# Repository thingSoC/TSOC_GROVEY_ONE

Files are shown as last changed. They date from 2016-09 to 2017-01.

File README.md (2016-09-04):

# TSOC_GROVEY_ONE
**TSOC_GROVEY_ONE** is a ATMEGA328 based board, an Embedded Module for thingSoC compatible with the Arduino IDE.

The **TSOC_GROVEY_ONE** allows you to connect [thingSoC](http://thingsoc.github.io/), [Mikrobus](http://www.mikroe.com/mikrobus/), 
and/or [Grove System](http://www.seeedstudio.com/blog/2016/03/09/tutorial-intro-to-grove-connectors-for-arduinoraspberry-pi-projects/) 
Modules all at the same time, using the Arduino Development environment, with the the ATMEGA328P processor.
This gives you maximum flexiblity for sensor and actuator, selection and reuse. 

The thingSoC "Grovey Series" was designed as "Everyday Electronics", a no-frills, low cost, approach to modular embedded product design.
thingSoC boards are similar in size to most break-out-boards (BOBs), but feature a standardized stacking pinout, as well as an I2C metadata store (EEPROM)
to indicate what peripherals are installed.

---------------------------------------

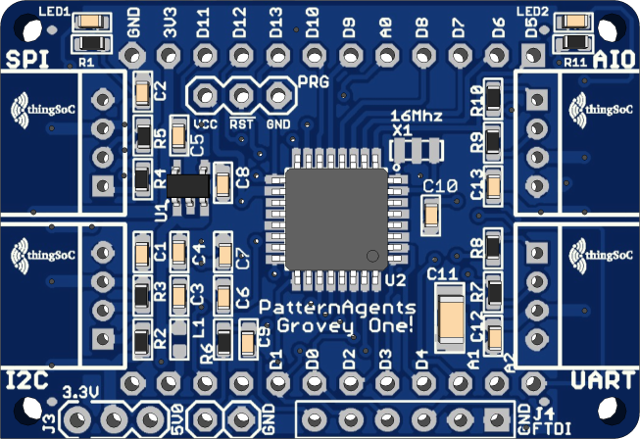
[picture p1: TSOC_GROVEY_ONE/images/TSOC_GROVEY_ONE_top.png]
thingSoC GROVEY_ONE
[TSOC_GROVEY_ONE](https://github.com/thingSoC/TSOC_GROVEY_ONE/)

* [thingSoC Compliant Module](http://www.thingsoc.com)
* [Mikrobus Compatible Module](http://www.mikroe.com/mikrobus/) 
* 5V Nominal Power Input
* 5V or 3.3V Operation
* Supports Analog  Inputs  (ADC) 
* Supports Digital Outputs (GPIO)
* Supports Digital Inputs  (GPIO)
* Supports I2C Interface
* Supports UART Interface
* Supports SPI Interface

---------------------------------------
## Example Applications

* [Weather Sensor](http://www.mikroe.com/click/weather/) BOSCH BME280 Temp, Humidity, Air Pressure
* [Methane Sensor](http://www.mikroe.com/click/methane/) MQ-4 Sensor for Methane (CH4) 
* [Air Quality Sensor](http://www.mikroe.com/click/air-quality/) MQ-135 Sensor for Harmful Gasses
* [Lightning Sensor](http://www.mikroe.com/click/thunder/) AS3935 Lighting Strike Detector
* [Controlled Relay](http://www.mikroe.com/click/relay/) G6D1AASI Power Relay Control Module

---------------------------------------
## 3D Model (Sketchup)

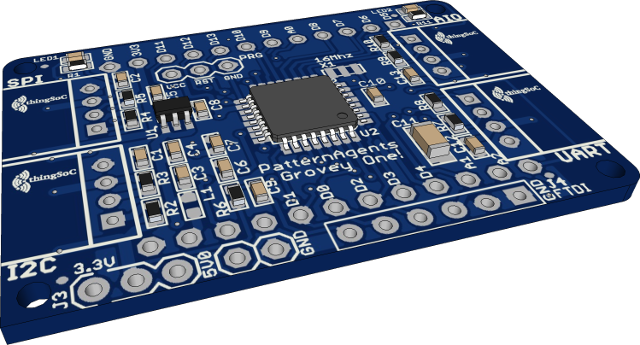
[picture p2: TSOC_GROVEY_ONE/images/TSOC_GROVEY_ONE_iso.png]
thingSoC TSOC_GROVEY_ONE


---------------------------------------
## Project Status

* 09/02/2016 : Revision 2.0 Release for PCB fab

## Revision 2.0 Notes: ##

* Add FTDI Connector

---------------------------------------

## Documentation Index <a name="documentation_index"/>

[Quick Start Guide](https://github.com/thingSoC/TSOC_GROVEY_ONE/blob/master/TSOC_GROVEY_ONE/docs/QuickStart.md)

[User Guide](https://github.com/thingSoC/TSOC_GROVEY_ONE/blob/master/TSOC_GROVEY_ONE/docs/UserGuide.md)

[Theory of Operation](https://github.com/thingSoC/TSOC_GROVEY_ONE/blob/master/TSOC_GROVEY_ONE/docs/TheoryOfOperation.md)

[thingSoC Organization Website](http://thingSoC.github.io)

[thingSoC FAQ - Frequently Asked Questions](http://thingsoc.github.io/support/faq.html)

---------------------------------------

[  
*thingSoC*](http://thingsoc.github.io)

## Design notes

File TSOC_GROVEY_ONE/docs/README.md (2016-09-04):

**TSOC_GROVEY_ONE** is a ATMEGA328 based board, an Embedded Module for thingSoC compatible with the Arduino IDE.

The **TSOC_GROVEY_ONE** allows you to connect [thingSoC](http://thingsoc.github.io/), [Mikrobus](http://www.mikroe.com/mikrobus/), 
and/or [Grove System](http://www.seeedstudio.com/blog/2016/03/09/tutorial-intro-to-grove-connectors-for-arduinoraspberry-pi-projects/) 
Modules all at the same time, using the Arduino Development environment, with the the ATMEGA328P processor.
This gives you maximum flexiblity for sensor and actuator, selection and reuse. 

[thingSoC GROVEY_ONETSOC_GROVEY_ONE](https://github.com/thingSoC/TSOC_GROVEY_ONE/)

The thingSoC "Grovey Series" was designed as "Everyday Electronics", a no-frills, low cost, approach to modular embedded product design.
thingSoC boards are similar in size to most break-out-boards (BOBs), but feature a standardized stacking pinout, as well as an I2C metadata store (EEPROM)
to indicate what peripherals are installed.

---------------------------------------

## Documentation Index <a name="documentation_index"/>

[[TSOC_GROVEY_ONE Quick Start Guide](https://github.com/thingSoC/TSOC_GROVEY_ONE/blob/master/TSOC_GROVEY_ONE/docs/QuickStart.md)

[TSOC_GROVEY_ONE User Guide](https://github.com/thingSoC/TSOC_GROVEY_ONE/blob/master/TSOC_GROVEY_ONE/docs/UserGuide.md)

[TSOC_GROVEY_ONE Theory of Operation](https://github.com/thingSoC/TSOC_GROVEY_ONE/blob/master/TSOC_GROVEY_ONE/docs/TheoryOfOperation.md)

[thingSoC Organization Website](http://thingSoC.github.io)

[thingSoC FAQ - Frequently Asked Questions](http://thingsoc.github.io/support/faq.html)

---------------------------------------

[  
*thingSoC*](http://thingsoc.github.io)

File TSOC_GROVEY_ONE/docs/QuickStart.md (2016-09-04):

# TSOC_GROVEY_ONE Quick Start Guide

Welcome! <br>
The **TSOC_GROVEY_ONE**  Quick Start Guide is a series of quick steps to try out your new board.

---------------------------------------

## Quick Start Guide <a name="quickstartguide_index"/>

1. Plug the **TSOC_GROVEY_ONE** into another thingSoC board, such as the Teensy3x or Grovey_WiFi
2. Plug a Peripheral into the **TSOC_GROVEY_ONE** and note which port number (there are four ports).
3. Open the Arduino IDE and Select "File -> Examples -> TSOC_GROVEY_ONE -> Port X  
   where X is the Port number that your installed your peripheral into
4. Follow the instructions on your screen to configure the TSOC_GROVEY_ONE for your application.

[thingSoC GROVEY_ONETSOC_GROVEY_ONE](https://github.com/thingSoC/TSOC_GROVEY_ONE/)

The thingSoC "Grovey Series" was designed as "Everyday Electronics", a no-frills, low cost, approach to modular embedded product design.
thingSoC boards are similar in size to most break-out-boards (BOBs), but feature a standardized stacking pinout, as well as an I2C metadata store (EEPROM)
to indicate what peripherals are installed.

---------------------------------------

## Documentation Index <a name="documentation_index"/>

[TSOC_GROVEY_ONE Quick Start Guide](https://github.com/thingSoC/TSOC_GROVEY_ONE/blob/master/TSOC_GROVEY_ONE/docs/QuickStart.md)

[TSOC_GROVEY_ONE User Guide](https://github.com/thingSoC/TSOC_GROVEY_ONE/blob/master/TSOC_GROVEY_ONE/docs/UserGuide.md)

[TSOC_GROVEY_ONE Theory of Operation](https://github.com/thingSoC/TSOC_GROVEY_ONE/blob/master/TSOC_GROVEY_ONE/docs/TheoryOfOperation.md)

[thingSoC Organization Website](http://thingSoC.github.io)

[thingSoC FAQ - Frequently Asked Questions](http://thingsoc.github.io/support/faq.html)

---------------------------------------

[  
*thingSoC*](http://thingsoc.github.io)

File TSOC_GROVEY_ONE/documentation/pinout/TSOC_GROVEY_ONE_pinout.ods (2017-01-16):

 |  |  |  | A3 | D5 | PWR | GND | D0 | D1 | PWR | GND
 |  |  |  | ANA | PWM | VCC | GND | RXD | TXD | VCC | GND
DEFAULT | PORT | ADC | PWM |  |  |  |  |  |  |  |  | DEFAULT | PORT | ADC | PWM | LEGEND
USER LED | D13 |  |  |  |  |  |  |  |  |  |  |  |  |  |  | POWER/GROUND PINS
IO2 | D5 |  | D5 |  |  |  |  |  |  |  |  | RI | A6 | A6 |  | DIGITAL PINS
IO1 | D6 |  | D6 |  |  |  |  |  |  |  |  | DCD | A2 | A2 |  | ANALOG/ADC PINS
SS2 | D7 |  |  |  |  |  |  |  |  |  |  | DSR | A1 | A1 |  | PWM PINS
SS1 | D8 |  |  |  |  |  |  |  |  |  |  | DTR | D4 |  |  | TOUCH PINS
IRQ | A0 | A0 |  |  |  |  |  |  |  |  |  | RTS | D3 |  | D3 | UART PINS
ATN | D9 |  | D9 |  |  |  |  |  |  |  |  | CTS | D2 |  |  | PROGRAM/JTAG/DEBUG PINS
SSEL | D10 |  | D10 |  |  |  |  |  |  |  |  | RXD | D0 |  |  | I2C BUS PINS
SCK | D13 | (PGM) |  |  |  |  |  |  |  |  |  | TXD | D1 |  |  | SPI BUS PINS
MISO | D12 | (PGM) |  |  |  |  |  |  |  |  |  | SCL | A5 | A5
MOSI | D11 | (PGM) | D11 |  |  |  |  |  |  |  |  | SDA | A4 | A4
3.3 VOLTS | 3V3 |  |  |  |  |  |  |  |  |  |  | 5.0 VOLTS | 5V0
GROUND | GND |  |  |  |  |  |  |  |  |  |  | GND | GND
POWER LED | VCC
 |  |  |  | GND | VCC | MOSI | SCK | GND | VCC | SDA | SCL |  |  |  | PatternAgents
 |  |  |  | GND | PWR | D11 | D13 | GND | PWR | A4 | A5 |  |  |  | http://github.com/thingsoc/
 |  |  |  |  |  |  |  |  |  |  |  |  |  |  | TSOC_GROVEY_ONE

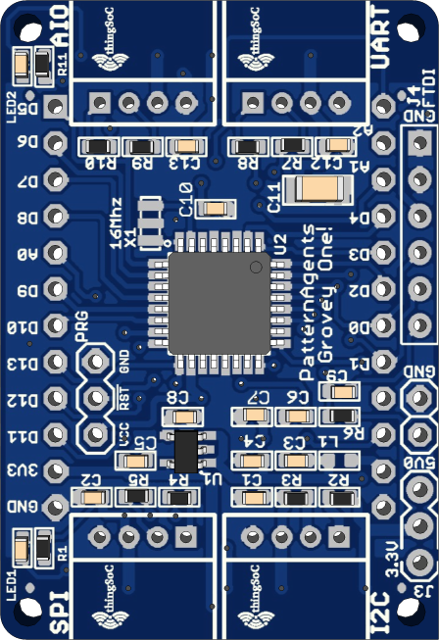
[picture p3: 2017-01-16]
TSOC_GROVEY_ONE/images/TSOC_GROVEY_ONE_pinout.png

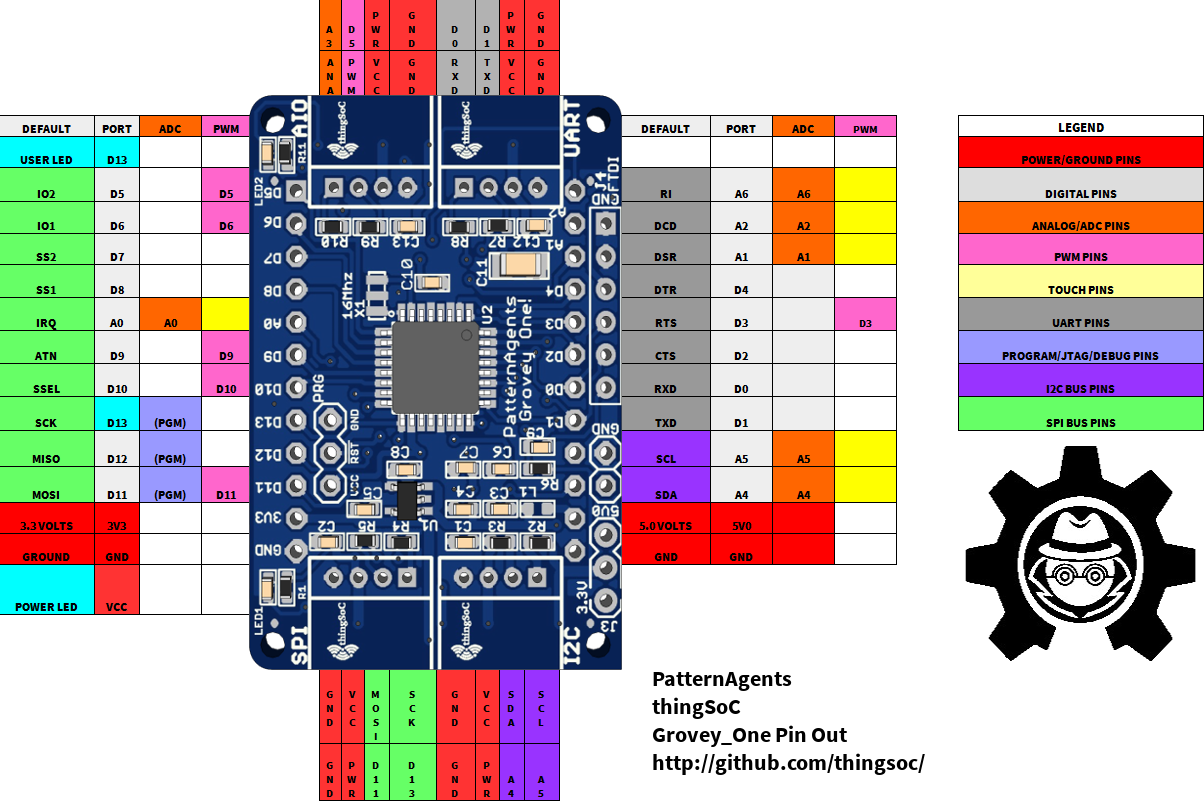
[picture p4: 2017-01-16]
TSOC_GROVEY_ONE/documentation/pinout/TSOC_GROVEY_ONE_pinout.png

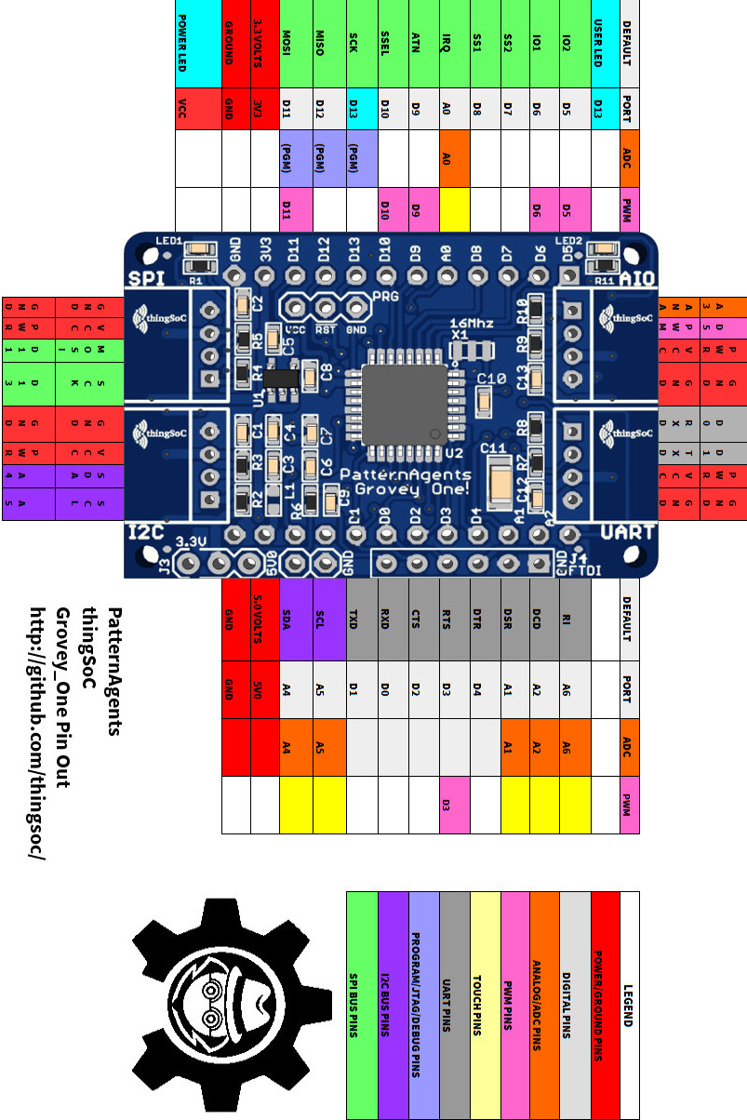
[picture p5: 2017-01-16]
TSOC_GROVEY_ONE/documentation/pinout/TSOC_GROVEY_ONE_pinout_long.jpg

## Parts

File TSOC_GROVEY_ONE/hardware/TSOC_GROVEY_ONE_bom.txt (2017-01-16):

Partlist exported from U:/PatternAgents/eagle/TSOC_Modules/TSOC_GROVEY_ONE/TSOC_GROVEY_ONE/TSOC_GROVEY_ONE.sch at 11/9/2016 3:23:07 PM
RFevison 2.0

Part  Value                Device                                          Package              Description                           BOM     MPN                 VALUE               
C1    100nf                CERAMIC-100NF-50V-10%-X7R(0603)                 C0603                302010138                                     CC0603KRX7R9BB104   100nf               
C2    100nf                CERAMIC-100NF-50V-10%-X7R(0603)                 C0603                302010138                                     CC0603KRX7R9BB104   100nf               
C3    10uf                 CERAMIC-10UF-10V-10%-X5R(0603)                  C0603                302010103                                     CC0603KRX5R6BB106   10uf                
C4    100nf                CERAMIC-100NF-50V-10%-X7R(0603)                 C0603                302010138                                     CC0603KRX7R9BB104   100nf               
C5    10uf                 CERAMIC-10UF-10V-10%-X5R(0603)                  C0603                302010103                                     CC0603KRX5R6BB106   10uf                
C6    100nf                CERAMIC-100NF-50V-10%-X7R(0603)                 C0603                302010138                                     CC0603KRX7R9BB104   100nf               
C7    100nf                CERAMIC-100NF-50V-10%-X7R(0603)                 C0603                302010138                                     CC0603KRX7R9BB104   100nf               
C8    470Pf                CERAMIC-100NF-50V-10%-X7R(0603)                 C0603                302010138                                     CC0603KRX7R9BB104   100nf               
C9    100nf                CERAMIC-100NF-50V-10%-X7R(0603)                 C0603                302010138                                     CC0603KRX7R9BB104   100nf               
C10   100nf                CERAMIC-100NF-50V-10%-X7R(0603)                 C0603                302010138                                     CC0603KRX7R9BB104   100nf               
C11   22uF                 CAP-1206                                        EIA-1206             Ceramic Capacitor SMD                                                                 
C12   100nf                CERAMIC-100NF-50V-10%-X7R(0603)                 C0603                302010138                                     CC0603KRX7R9BB104   100nf               
C13   100nf                CERAMIC-100NF-50V-10%-X7R(0603)                 C0603                302010138                                     CC0603KRX7R9BB104   100nf               
R1    1K 1/10W             SMD-RES-1K-5%-1/10W(0603)                       R0603                301010291                                     RC0603JR-071KL      1K 1/10W            
R2    2.2K                 SMD-RES-2.2K-5%-1/10W(0603)                     R0603                301010124                                     RC0603JR-072K2L     2.2K                
R3    2.2K                 SMD-RES-2.2K-5%-1/10W(0603)                     R0603                301010124                                     RC0603JR-072K2L     2.2K                
R4    1K 1/10W             SMD-RES-1K-5%-1/10W(0603)                       R0603                301010291                                     RC0603JR-071KL      1K 1/10W            
R5    1K 1/10W             SMD-RES-1K-5%-1/10W(0603)                       R0603                301010291                                     RC0603JR-071KL      1K 1/10W            
R6    10K 1/10W            SMD-RES-10K-5%-1/10W(0603)                      R0603                301010293                                     RC0603JR-0710KL     10K 1/10W           
R7    1K 1/10W             SMD-RES-1K-5%-1/10W(0603)                       R0603                301010291                                     RC0603JR-071KL      1K 1/10W            
R8    1K 1/10W             SMD-RES-1K-5%-1/10W(0603)                       R0603                301010291                                     RC0603JR-071KL      1K 1/10W            
R9    1K 1/10W             SMD-RES-1K-5%-1/10W(0603)                       R0603                301010291                                     RC0603JR-071KL      1K 1/10W            
R10   1K 1/10W             SMD-RES-1K-5%-1/10W(0603)                       R0603                301010291                                     RC0603JR-071KL      1K 1/10W            
R11   1K 1/10W             SMD-RES-1K-5%-1/10W(0603)                       R0603                301010291                                     RC0603JR-071KL      1K 1/10W            
L1    120OHM-500MA         SMD-FERRITE-CHIP-120-OHM-500MA(0603)            L0603                303030001                                     BLM18AG121SN1D      120OHM-500MA        
X1    16MHZ                SMD-RESONATOR-16MHZ-15PF-0.5%-40R(3P-3.2X1.3MM) X3-SMD-3.6X1.3X0.8MM 306030002                                     CSTCE16M0V53-R0     16MHZ               
LED1  GREEN-0603           SMD-LED-CLEAR-GREEN(0603)                       LED-0603             304090043                                     19-217-G7C-AN1P2-3T GREEN-0603          
LED2  RED-0603             SMD-LED-CLEAR-GREEN(0603)                       LED-0603             304090043                                     19-217-G7C-AN1P2-3T GREEN-0603          
U1    MIC5219              PMIC-LDO                                        SOT-23-5                                                           MIC5219-3.3V        MIC5219-3.3V
U2    ATMEGA328            ATMEGA168                                       TQFP32-08                                                                                                  
AIO   4P-2.0-90D           GROVE-CONNECTOR-DIP-90D(4P-2.0)                 HW4-2.0-90D          320110034                                                         4P-2.0-90D          
I2C   4P-2.0-90D           GROVE-CONNECTOR-DIP-90D(4P-2.0)                 HW4-2.0-90D          320110034                                                         4P-2.0-90D          
SPI   4P-2.0-90D           GROVE-CONNECTOR-DIP-90D(4P-2.0)                 HW4-2.0-90D          320110034                                                         4P-2.0-90D          
UART  4P-2.0-90D           GROVE-CONNECTOR-DIP-90D(4P-2.0)                 HW4-2.0-90D          320110034                                                         4P-2.0-90D          
J3    NO                   JMP-3-NO-PTH                                    JMP-3-NO-PTH-2.54    Three Terminal Jumper - Normally Open                                                 
J4    6p-2.54              DIP-BLACK-MALE-HEADER(6P-2.54)                  H6-2.54              320020078                                     P125-1106A1BS116A1  6p-2.54

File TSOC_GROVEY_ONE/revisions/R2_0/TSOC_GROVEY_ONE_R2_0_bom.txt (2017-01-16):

Partlist exported from U:/PatternAgents/eagle/TSOC_Modules/TSOC_GROVEY_ONE/TSOC_GROVEY_ONE/revisions/R2_0/TSOC_GROVEY_ONE_R2_0_gerbers/TSOC_GROVEY_ONE.sch at 12/29/2016 11:41:01 AM

Qty Value             Device                                          Package              Parts                                 Description                           
1                     JMP-2-NO                                        JMP-2-NO             A7                                    Two Terminal Jumper - Normally Open   
2                     M01PTH                                          1X01                 5V0, GND                              Header 1                              
1                     M03PTH                                          1X03                 PRG                                   Header 3                              
9   100nf             CERAMIC-100NF-50V-10%-X7R(0603)                 C0603                C1, C2, C4, C6, C7, C9, C10, C12, C13 302010138                             
1   10K 1/10W         SMD-RES-10K-5%-1/10W(0603)                      R0603                R6                                    301010293                             
2   10uf              CERAMIC-10UF-10V-10%-X5R(0603)                  C0603                C3, C5                                302010103                             
1   120OHM-500MA      SMD-FERRITE-CHIP-120-OHM-500MA(0603)            L0603                L1                                    303030001                             
1   16MHZ             SMD-RESONATOR-16MHZ-15PF-0.5%-40R(3P-3.2X1.3MM) X3-SMD-3.6X1.3X0.8MM X1                                    306030002                             
8   1K 1/10W          SMD-RES-1K-5%-1/10W(0603)                       R0603                R1, R4, R5, R7, R8, R9, R10, R11      301010291                             
2   2.2K              SMD-RES-2.2K-5%-1/10W(0603)                     R0603                R2, R3                                301010124                             
1   22uF              CAP-1206                                        EIA-1206             C11                                   Ceramic Capacitor SMD                 
1   470Pf             CERAMIC-100NF-50V-10%-X7R(0603)                 C0603                C8                                    302010138                             
4   4P-2.0-90D        GROVE-CONNECTOR-DIP-90D(4P-2.0)                 HW4-2.0-90D          AIO, I2C, SPI, UART                   320110034                             
1   6p-2.54           DIP-BLACK-MALE-HEADER(6P-2.54)                  H6-2.54              J4                                    320020078                             
1   AP2112K-3.3V      V_REG_LDOSMD                                    SOT23-5              U1                                    Voltage Regulator LDO                 
1   ATMEGA328         ATMEGA168                                       TQFP32-08            U2                                                                          
4   FIDUCIALUFIDUCIAL FIDUCIALUFIDUCIAL                               MICRO-FIDUCIAL       FID1, FID2, FID3, FID4                Fiducial Alignment Points             
1   GREEN-0603        SMD-LED-CLEAR-GREEN(0603)                       LED-0603             LED1                                  304090043                             
1   NO                JMP-3-NO-PTH                                    JMP-3-NO-PTH-2.54    J3                                    Three Terminal Jumper - Normally Open 
1   RED-0603          SMD-LED-CLEAR-GREEN(0603)                       LED-0603             LED2                                  304090043                             
1   TSOC-24-BB        TSOC-24-BB                                      TSOC-BB-S24          TSOC                                  thingSoC Twenty-Four(24) Pin Socket   
1   TSOC-LOGO-LRG     TSOC-LOGO-LRG                                   TSOC-LOGO-LRG        U$102                                 thingSoC Logo                         
3   TSOC-LOGO-SMALL   TSOC-LOGO-SMALL                                 TSOC-LOGO-SML        U$1, U$101, U$103                     thingSoC Logo                         
1   TSOC-PCB-SINGLE   TSOC-PCB-SINGLE                                 TSOC-BB-BRD-DIM      $$U$1                                 thingSoC PCB Outlines

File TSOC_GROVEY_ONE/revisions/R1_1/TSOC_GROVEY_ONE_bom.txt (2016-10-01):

Partlist exported from U:/PatternAgents/eagle/TSOC_Modules/TSOC_GROVEY_ONE/TSOC_GROVEY_ONE/TSOC_GROVEY_ONE.sch Revison 1.1 at 9/29/2016 11:40:15 AM

Qty Value             Device                                          Package            Parts                                 Description                           
9   100nf             CERAMIC-100NF-50V-10%-X7R(0603)         C0603              C1, C2, C4, C6, C7, C9, C10, C12, C13 302010138                             
1   10K 1/10W         SMD-RES-10K-5%-1/10W(0603)              R0603              R6                                    301010293                             
2   10uf              CERAMIC-10UF-10V-10%-X5R(0603)          C0603              C3, C5                                302010103                             
2   120OHM-500MA      SMD-FERRITE-CHIP-120-OHM-500MA(0603)    L0603              L1, L2                                303030001                             
1   16MHZ             SMD-RESONATOR-16MHZ-15PF-0.5%-40R       X3-SMD             X1                                    306030002                             
8   1K 1/10W          SMD-RES-1K-5%-1/10W(0603)               R0603              R1, R11,R4, R5, R7, R8, R9, R10       301010291                             
2   2.2K              SMD-RES-2.2K-5%-1/10W(0603)             R0603              R2, R3                                301010124                             
1   22uF              CAP-1206                                EIA-1206           C11                                   Ceramic Cap                
1   470Pf             CERAMIC-100NF-50V-10%-X7R(0603)         C0603              C8                                    302010138                             
1   GREEN-0603        SMD-LED-CLEAR-GREEN(0603)               LED-0603           LED1                                  304090043                             
1   RED-0603          SMD-LED-CLEAR-GREEN(0603)               LED-0603           LED2                                  304090043                             
1   ATMEGA328         ATMEGA168                               TQFP32-08          U2                                                                          
1   MIC5219 3.3V      V_REG_MIC52193.3V                       SOT23-5            U1                                    V_REG MIC5219                         

Optional Parts (Do NOT Install on Production Boards)
----------------------------------------------------------------------------------------------------------------------------------------------
4   4P-2.0-90D        GROVE-CONNECTOR-DIP-90D(4P-2.0)         HW4-2.0-90D        J1, J2, J5, J6                        320110034                             
1   6p-2.54           DIP-BLACK-MALE-HEADER(6P-2.54)          H6-2.54            J4                                    320020078                             
1   NO                JMP-3-NO-PTH                            JMP-3-NO-PTH-2.54  J3                                    Three Terminal Jumper 
1                     M03PTH                                  1X03               PRG                                   Header 3                              
1                     M01PTH                                  1X01               GND                                   Header 1                              
1                     JMP-2-NO                                JMP-2-NO           A7                                    Two Terminal Jumper 
----------------------------------------------------------------------------------------------------------------------------------------------

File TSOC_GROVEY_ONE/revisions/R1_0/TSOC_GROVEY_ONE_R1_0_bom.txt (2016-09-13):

Partlist exported from U:/PatternAgents/eagle/TSOC_Modules/TSOC_GROVEY_ONE/TSOC_GROVEY_ONE/TSOC_GROVEY_ONE.sch Revison 1.0 at 9/2/2016 10:40:15 AM

Qty Value             Device                                          Package            Parts                                 Description                           
9   100nf             CERAMIC-100NF-50V-10%-X7R(0603)         C0603              C1, C2, C4, C6, C7, C9, C10, C12, C13 302010138                             
1   10K 1/10W         SMD-RES-10K-5%-1/10W(0603)              R0603              R6                                    301010293                             
2   10uf              CERAMIC-10UF-10V-10%-X5R(0603)          C0603              C3, C5                                302010103                             
2   120OHM-500MA      SMD-FERRITE-CHIP-120-OHM-500MA(0603)    L0603              L1, L2                                303030001                             
1   16MHZ             SMD-RESONATOR-16MHZ-15PF-0.5%-40R       X3-SMD             X1                                    306030002                             
2   1K 1/10W          SMD-RES-1K-5%-1/10W(0603)               R0603              R1, R11                               301010291                             
2   2.2K              SMD-RES-2.2K-5%-1/10W(0603)             R0603              R2, R3,                               301010124                             
1   22uF              CAP-1206                                EIA-1206           C11                                   Ceramic Cap                
1   470Pf             CERAMIC-100NF-50V-10%-X7R(0603)         C0603              C8                                    302010138                             
1   GREEN-0603        SMD-LED-CLEAR-GREEN(0603)               LED-0603           LED1                                  304090043                             
1   RED-0603          SMD-LED-CLEAR-GREEN(0603)               LED-0603           LED2                                  304090043                             
4   4P-2.0-90D        GROVE-CONNECTOR-DIP-90D(4P-2.0)         HW4-2.0-90D        J1, J2, J5, J6                        320110034                             
1   ATMEGA328         ATMEGA168                               TQFP32-08          U2                                                                          
1   MIC5219 3.3V      V_REG_MIC52193.3V                       SOT23-5            U1                                    V_REG MIC5219                         

Optional Parts (Do NOT Install on Production Boards)
----------------------------------------------------------------------------------------------------------------------------------------------
6   2.2K              SMD-RES-2.2K-5%-1/10W(0603)             R0603              R4, R5, R7, R8, R9, R10               301010124                             
1   6p-2.54           DIP-BLACK-MALE-HEADER(6P-2.54)          H6-2.54            J4                                    320020078                             
1   NO                JMP-3-NO-PTH                            JMP-3-NO-PTH-2.54  J3                                    Three Terminal Jumper 
1                     M03PTH                                  1X03               PRG                                   Header 3                              
1                     M01PTH                                  1X01               GND                                   Header 1                              
1                     JMP-2-NO                                JMP-2-NO           A7                                    Two Terminal Jumper 
----------------------------------------------------------------------------------------------------------------------------------------------

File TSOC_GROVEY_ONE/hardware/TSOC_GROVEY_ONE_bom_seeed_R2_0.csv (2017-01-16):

Part/Designator | Manufacture Part Number/Seeed SKU | Quantity
C1,C2,C4,C6,C7,C9,C10,C12,C13 | 302010138 | 9
C3,C5 | 302010103 | 2
C8 | 302010141 | 1
C11 | 302010183 | 1
R2,R3 | 301010124 | 2
R1,R4,R5,R7,R8,R9,R10,R11 | 301010291 | 8
R6 | 301010293 | 1
LED1 | 304090043 | 1
LED2 | 304090045 | 1
L1 | 303030001 | 1
X1 | 306030002 | 1
U1 | 310030046 | 1
U2 | 1030060P1 | 1
AIO,I2C,SPI,UART | 3470140P1 | 4
J4 | 320020078 | 1
J3 | 320020079 | 1

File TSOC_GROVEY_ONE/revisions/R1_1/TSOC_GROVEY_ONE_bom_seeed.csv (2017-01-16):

Part/Designator | Manufacture Part Number/Seeed SKU | Quantity
C1,C2,C4,C6,C7,C9,C10,C12,C13 | 302010138 | 9
C3,C5 | 302010103 | 2
C8 | 302010141 | 1
C11 | 302010183 | 1
R1,R11 | 301010291 | 2
R4,R5,R7,R8,R9,R10 | 301010124 | 6
R2,R3,R6 | 301010293 | 3
LED1 | 304090043 | 1
LED2 | 304090045 | 1
L1 | 303030001 | 1
X1 | 306030002 | 1
U1 | AP2112K-3.3TRG1 | 1
U2 | 310010049 | 1
AIO,I2C,SPI,UART | 320110034 | 4
J1,J2 | PPTC121LFBN-RC | 2
J3 | 320020079 | 1
J4 | 320020078 | 1

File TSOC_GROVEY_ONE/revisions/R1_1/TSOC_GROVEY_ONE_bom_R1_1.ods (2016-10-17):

Qty | Value | Device | Package | Parts | Seeed Pt# | Digikey # | Digikey $/ea | MOQ | # have
9 | 100nf | CERAMIC-100NF-50V-10%-X7R(0603) | C0603 | C1, C2, C4, C6, C7, C9, C10, C12, C13 | 302010138 | 490-1524-2-ND | $0.00368 | 4000 | 3736
1 | 470Pf | CERAMIC-100NF-50V-10%-X7R(0603) | C0603 | C8 |  | 1276-1168-2-ND | $0.00451 | 4000 | Minireel 467
2 | 10uf | CERAMIC-10UF-10V-10%-X5R(0603) | C0603 | C3, C5 | 302010103 | 490-10474-2-ND | $0.02688 | 4000 | 6
1 | 22uF | CAP-1206 | EIA-1206 | C11 |  | 478-9946-1-ND | $0.38520 | 25 | Minireel 188
8 | 1K 1/10W | SMD-RES-1K-5%-1/10W(0603) | R0603 | R1, R4, R5, R7, R8, R9, R10, R11 | 301010291 | RMCF0603JT1K00 | $0.00158 | 5000 | 4922
2 | 2.2K | SMD-RES-2.2K-5%-1/10W(0603) | R0603 | R2, R3 | 301010124 | RMCF0603JT2K20TR-ND | $0.00158 | 5000 | 4872
1 | 10K 1/10W | SMD-RES-10K-5%-1/10W(0603) | R0603 | R6 | 301010293 | RMCF0603JT10K0TR-ND | $0.00158 | 5000 | 4864
1 | 120OHM-500MA | SMD-FERRITE-CHIP-120-OHM-500MA(0603) | L0603 | L1 | 303030001
1 | 16MHZ | SMD-RESONATOR-16MHZ-15PF-0.5%-40R(3P-3.2X1.3MM) | X3-SMD-3.6X1.3X0.8MM | X1 | 306030002 | 490-1198-1-ND | $0.48 | 1 | 5
1 | GREEN-0603 | SMD-LED-CLEAR-GREEN(0603) | LED-0603 | LED1 |  | 475-3118-1-ND | $0.35 | 1 | 15
1 | RED-0603 | SMD-LED-CLEAR-RED(0603) | LED-0603 | LED2 | 304090043 | 475-2506-1-ND | $0.35 | 1 | 8
1 | MIC5219 3.3V | V_REG_MIC52193.3V | SOT23-5 | U1 |  | 576-1281-1-ND | $0.89 | 1 | 30
1 | ATMEGA328 | ATMEGA168 | TQFP32-08 | U2 |  | ATMEGA328P-AURCT-ND | $3.81 | 1 | 4
1 | TSOC-PCB-SINGLE | TSOC-PCB-SINGLE | TSOC-BB-BRD-DIM | PCB |  |  | $4.00
2 | F12X1 | CONN HEADER FEM 12POS.1' SGL TIN | F12X1 | J7, J8 | S6100-ND | S6100-ND | $0.98 | 1 | 12
4 | 4P-2.0-90D | GROVE-Universal CONNECTOR-DIP-90D(4P-2.0) | HW4-2.0-90D | AIO, I2C, SPI, UART | 320110034 | SEEED110990037 | $0.15
1 | 6p-2.54 | DIP-BLACK-MALE-HEADER(6P-2.54) | H6-2.54 | J4 | 320020078 |  | $0.25 | 1

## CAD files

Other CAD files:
TSOC_GROVEY_ONE/eagleUp/TSOC_GROVEY_ONE.skp

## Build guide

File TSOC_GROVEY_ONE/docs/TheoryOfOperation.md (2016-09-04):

# TSOC_GROVEY_ONE Theory of Operation

**TSOC_GROVEY_ONE** is a ATMEGA328 based board, an Embedded Module for thingSoC compatible with the Arduino IDE.

The **TSOC_GROVEY_ONE** allows you to connect [thingSoC](http://thingsoc.github.io/), [Mikrobus](http://www.mikroe.com/mikrobus/), 
and/or [Grove System](http://www.seeedstudio.com/blog/2016/03/09/tutorial-intro-to-grove-connectors-for-arduinoraspberry-pi-projects/) 
Modules all at the same time, using the Arduino Development environment, with the the ATMEGA328P processor.
This gives you maximum flexiblity for sensor and actuator, selection and reuse. 

[thingSoC GROVEY_ONETSOC_GROVEY_ONE](https://github.com/thingSoC/TSOC_GROVEY_ONE/)

The thingSoC "Grovey Series" was designed as "Everyday Electronics", a no-frills, low cost, approach to modular embedded product design.
thingSoC boards are similar in size to most break-out-boards (BOBs), but feature a standardized stacking pinout, as well as an I2C metadata store (EEPROM)
to indicate what peripherals are installed.

* [Supported by the Arduino IDE](https://www.arduino.cc/) 
* [thingSoC Compliant Module](http://www.thingsoc.com)
* [Mikrobus Compatible Module](http://www.mikroe.com/mikrobus/) 

---------------------------------------

## Theory of Operation <a name="theory_index"/>

The **TSOC_GROVEY_ONE** supports a single "thingSoC" socket with 3.3 Volt Level signaling.

### Page A : ThingSoC Interface <a name="PAGEA"/>

Schematic Page A

Limitations: 

### Page B : I2C Hub Controller <a name="PAGEB"/>

Schematic Page B

### Page C <a name="PAGEC"/>

Schematic Page C

### Page D <a name="PAGED"/>

Schematic Page D

---------------------------------------

## Documentation Index <a name="documentation_index"/>

[[TSOC_GROVEY_ONE Quick Start Guide](https://github.com/thingSoC/TSOC_GROVEY_ONE/blob/master/TSOC_GROVEY_ONE/docs/QuickStart.md)

[TSOC_GROVEY_ONE User Guide](https://github.com/thingSoC/TSOC_GROVEY_ONE/blob/master/TSOC_GROVEY_ONE/docs/UserGuide.md)

[TSOC_GROVEY_ONE Theory of Operation](https://github.com/thingSoC/TSOC_GROVEY_ONE/blob/master/TSOC_GROVEY_ONE/docs/TheoryOfOperation.md)

[thingSoC Organization Website](http://thingSoC.github.io)

[thingSoC FAQ - Frequently Asked Questions](http://thingsoc.github.io/support/faq.html)
[ESP8266 Community](https://github.com/esp8266/Arduino)

---------------------------------------

[  
*thingSoC*](http://thingsoc.github.io)

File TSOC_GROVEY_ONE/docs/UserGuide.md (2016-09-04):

# TSOC_GROVEY_ONE User Guide

**TSOC_GROVEY_ONE** is a four(4) port I2C Hub/Switch board, an Embedded Module for thingSoC.

The **TSOC_GROVEY_ONE** can operate at either 3.3V or 5V, and can also level translate 3.3V processor I2C bus to 5V peripherals when needed.

The **TSOC_GROVEY_ONE** allows you to connect [thingSoC](http://thingsoc.github.io/), [Mikrobus](http://www.mikroe.com/mikrobus/), 
and/or [Grove System](http://www.seeedstudio.com/blog/2016/03/09/tutorial-intro-to-grove-connectors-for-arduinoraspberry-pi-projects/) 
Modules all at the same time, with any processor module.
This gives you maximum flexiblity for sensor and actuator selection, and reuse. 

---------------------------------------

## User Guide <a name="userguide_index"/>

[thingSoC GROVEY_ONETSOC_GROVEY_ONE](https://github.com/thingSoC/TSOC_GROVEY_ONE/)

---------------------------------------

## Documentation Index <a name="documentation_index"/>

[TSOC_GROVEY_ONE Quick Start Guide](https://github.com/thingSoC/TSOC_GROVEY_ONE/blob/master/TSOC_GROVEY_ONE/docs/QuickStart.md)

[TSOC_GROVEY_ONE User Guide](https://github.com/thingSoC/TSOC_GROVEY_ONE/blob/master/TSOC_GROVEY_ONE/docs/UserGuide.md)

[TSOC_GROVEY_ONE Theory of Operation](https://github.com/thingSoC/TSOC_GROVEY_ONE/blob/master/TSOC_GROVEY_ONE/docs/TheoryOfOperation.md)

[thingSoC Organization Website](http://thingSoC.github.io)

[thingSoC FAQ - Frequently Asked Questions](http://thingsoc.github.io/support/faq.html)

---------------------------------------

[  
*thingSoC*](http://thingsoc.github.io)

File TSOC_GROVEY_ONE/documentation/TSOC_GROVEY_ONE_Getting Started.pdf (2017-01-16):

### Welcome to the thingSoC® Grovey One

The TSOC_GROVEY_ONE is an Arduino Uno compatible board, based on the Atmel ATMEGA328P chip, in an Embedded Module format for the new thingSoC, Internet of Things open source hardware standard.
Getting Started :
The TSOC_GROVEY_ONE is very flexible, and there are a number of different ways to power and reprogram the board, including using a thingSoC USBUART, or other "FTDI" type USB to UART adapters, as well as JTAG/SWD/SPI interfaces for "bare metal" programming.

Using a Li-Po Battery or Wall Power (5V) Adapter :
1) Set the VCC Jumper (Jx) to 3.3 Volts (left position as shown)
2) Using either a thingSoC USB power cable, connect a 5V power source to the Grovey One as shown below :

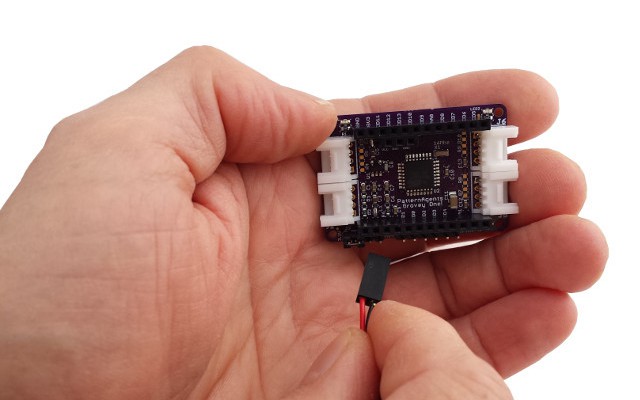
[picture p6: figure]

3) Note that this is the prefered combination for using 3.3 Volt Grove and Mikrobus peripherals, as it provides the correct voltage levels for all 3.3 Volt peripherals.
4) LED2 will illuminate (indicating VCC is powered), and LED1 (D13) will begin to blink slowly.

Using a Standard "FTDI" USB to UART Adapter :
1) Set the VCC Jumper (Jx) to either 3.3 Volts (bottom position)
or 5.0 Volt (top position) depending on you choice of peripherals.
Note that you can't mix voltages, the system is either 3.3 Volts or 5.0 Volts on ALL pins.
2) Plug an "FTDI" type USB to UART into the Grovey One such as the
Sparkfun 5.0 Volt "FTDI Basic" for 5.0 Volt VCC, or the
Sparkfun 3.3 Volt "FTDI Basic" for 3.3 Volt VCC,
and connect the USB cable to your computer.
Note that we use a six (6) pin right angle connector below, or you can just plug it in vertically.

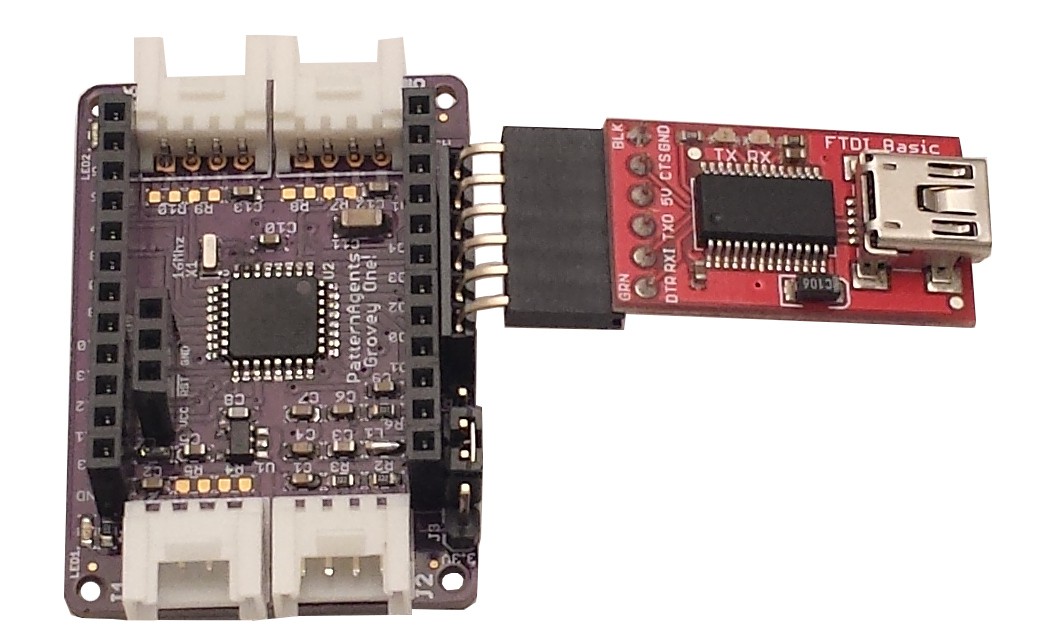
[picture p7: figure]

3) In the Arduino IDE, select the "Tools -> Board" type as "Arduino Pro or Pro Mini"
4) In the Arduino IDE, select the "Tools -> Processor" type as either
"ATMEGA328 5V 16Mhz" or "ATMEGA328 3.3V 8Mhz" depending on your VCC jumper setting.
5) In the Arduino IDE, select the "Tools -> Port" as COMx: where X is your FTDI adapter.
6) Now you are ready to program your Grovey One using the Arduino IDE.

Using an ICSP Programmer for Bare Metal Programming :

The TSOC_GROVEY_ONE board comes preloaded with the OPTIBOOT bootloader for Arduino, but if you prefer to do bare metal programming, connect an ICSP programmer as shown below. NOTE: the pinout is NOT the same as the default Arduino Pro board (due to space limitations).

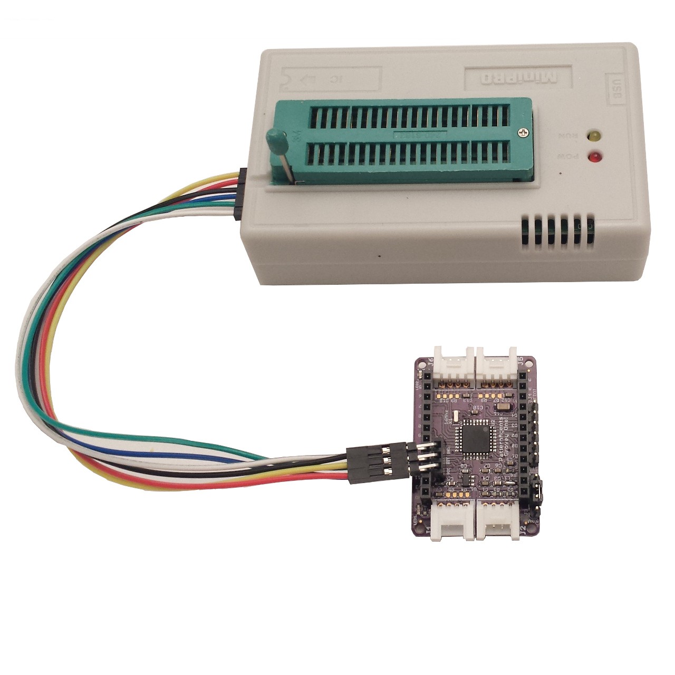
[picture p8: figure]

Grovey One
ICSP Pinout
| VCC - | - D11 |
| RST - | - D12 |
| GND - | - D13 |

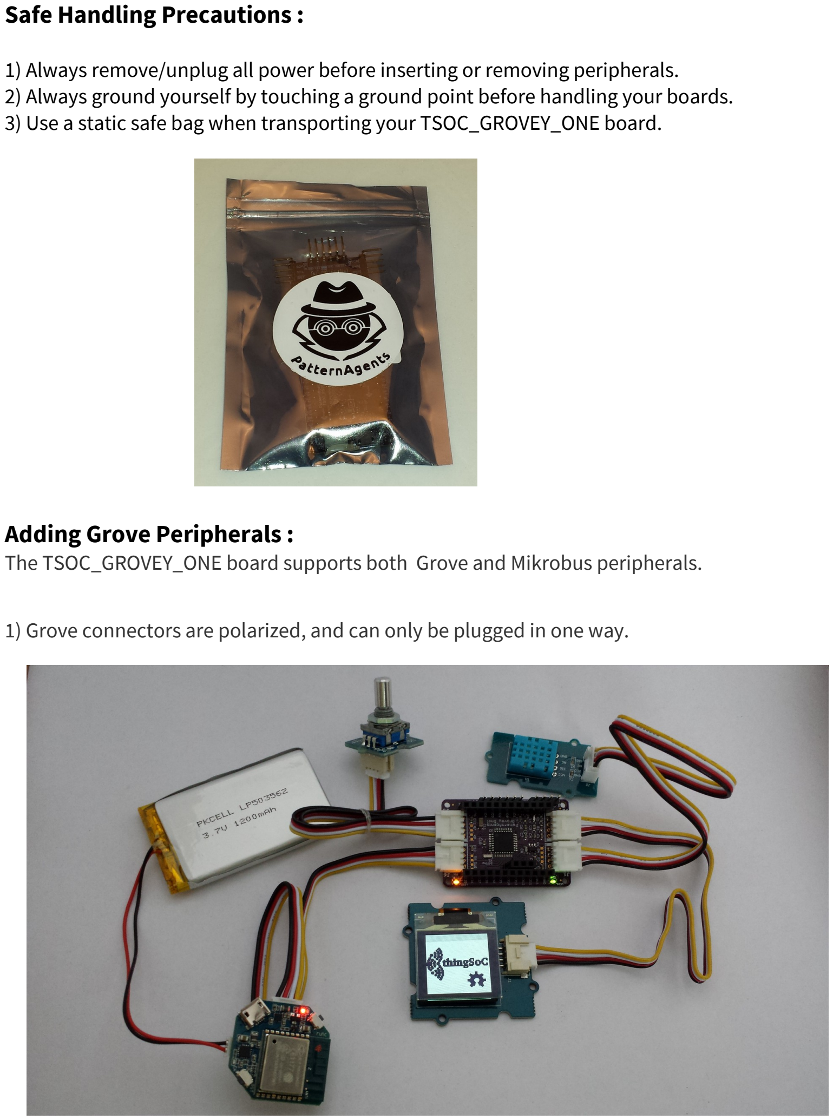
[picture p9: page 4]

Safe Handling Precautions :

1) Always remove/unplug all power before inserting or removing peripherals.
2) Always ground yourself by touching a ground point before handling your boards.
3) Use a static safe bag when transporting your TSOC_GROVEY_ONE board.

Adding Grove Peripherals :
The TSOC_GROVEY_ONE board supports both Grove and Mikrobus peripherals.
1) Grove connectors are polarized, and can only be plugged in one way.

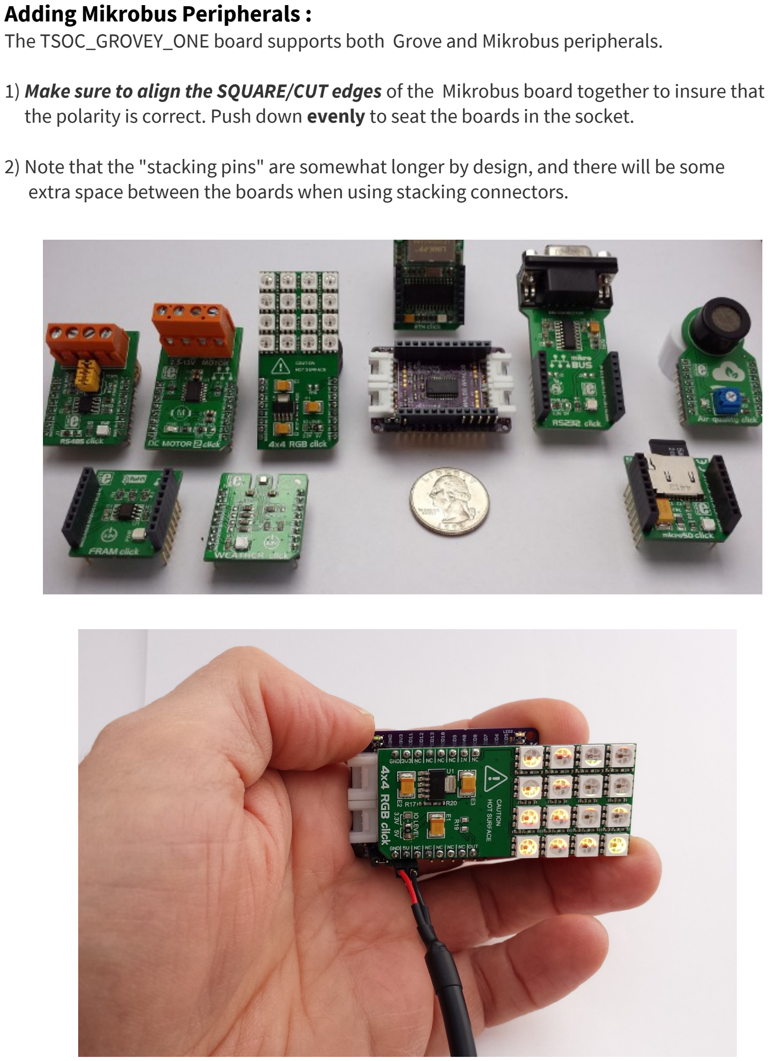
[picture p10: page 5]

Adding Mikrobus Peripherals :
The TSOC_GROVEY_ONE board supports both Grove and Mikrobus peripherals.
1) Make sure to align the SQUARE/CUT edges of the Mikrobus board together to insure that the polarity is correct. Push down evenly to seat the boards in the socket.
2) Note that the "stacking pins" are somewhat longer by design, and there will be some extra space between the boards when using stacking connectors.

### thingSoC® Grovey One Arduino Examples :

### Default Firmware :

1) The Grovey One comes preloaded with the basic "Blink" project. LED1 will blink slowly, indicating the sketch is running.

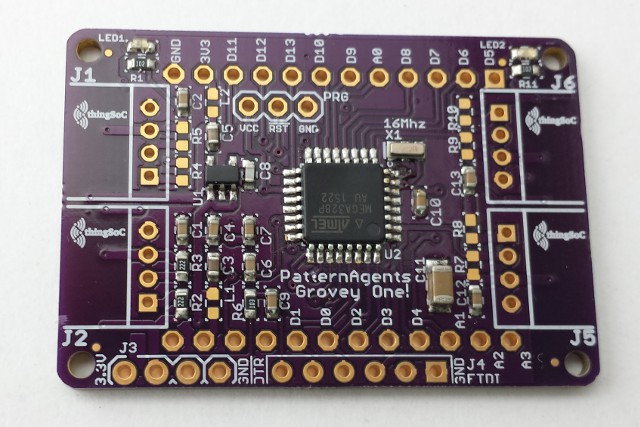
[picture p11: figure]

### For more information and examples :

Complete documentation, including schematics, layouts, gerbers, and Bill of Materials (BOM) are available on the thingSoC website at :

https://github.com/thingSoC/TSOC_GROVEY_ONE/tree/master/TSOC_GROVEY_ONE (https://github.com/thingSoC/TSOC_PSoC4L/tree/master/TSOC_PSoC4L)

There is also a project Wiki available for asking questions and more information at :

https://github.com/thingSoC/TSOC_GROVEY_ONE/wiki (https://github.com/thingSoC/TSOC_PSoC4L/wiki)

thingSoC® Grovey One Features :
The TSOC_GROVEY_ONE is a low cost, embeddable module featuring an ATMEGA328P device :
- Atmel ATMEGA328P (AVR) Processor
- 8 or 16 Mhz operation
- 3.3 Volt or 5.0 Volt operation
- 32 KiB FLASH memory
- 2 KiB SRAM
- 1 KiB EEPROM
- 3.3 Volt onboard voltage regulator
- 10-bit Analog to Digital Converter (8 Channels)
- Touch Sensing (8 Channels)
- SPI (1 Channel)
- I2C (1 Channel)
- UART (1 Channel)
- Power and USER LEDs
- thingSoC Compliant Module
- Mikrobus Compatible Module (http://www.mikroe.com/mikrobus/)

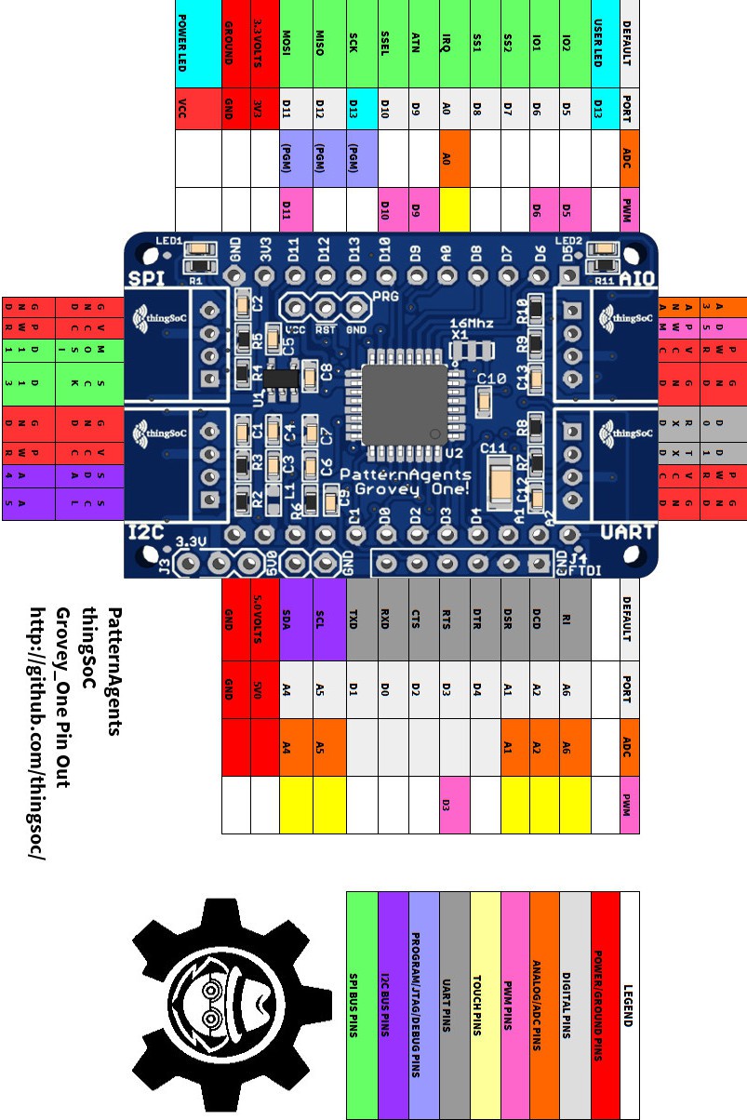
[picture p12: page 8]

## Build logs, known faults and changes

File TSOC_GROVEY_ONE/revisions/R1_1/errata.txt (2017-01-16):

Errata :

1) UART Silkscreen text reverese TXD/RXD - signals are okay

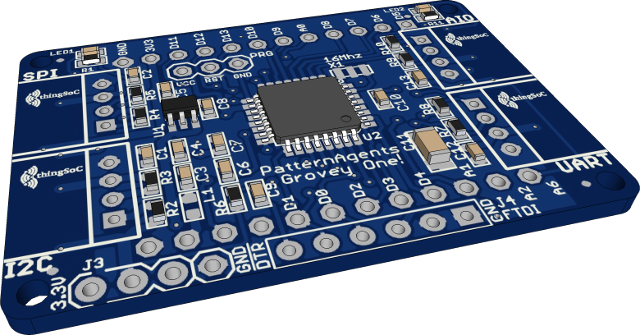
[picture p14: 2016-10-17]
TSOC_GROVEY_ONE/revisions/R1_1/images/TSOC_GROVEY_ONE_iso.png

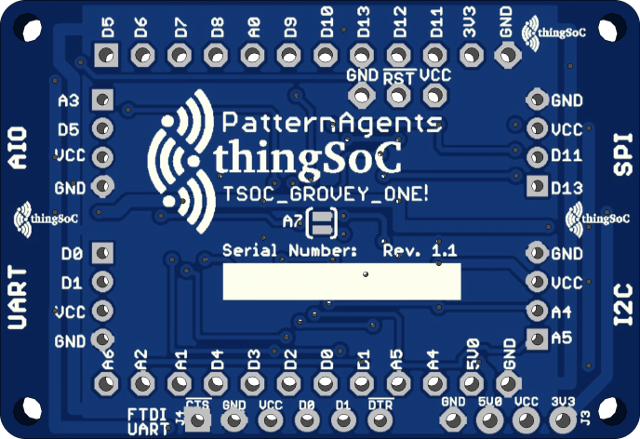
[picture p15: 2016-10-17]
TSOC_GROVEY_ONE/revisions/R1_1/images/TSOC_GROVEY_ONE_bot.png

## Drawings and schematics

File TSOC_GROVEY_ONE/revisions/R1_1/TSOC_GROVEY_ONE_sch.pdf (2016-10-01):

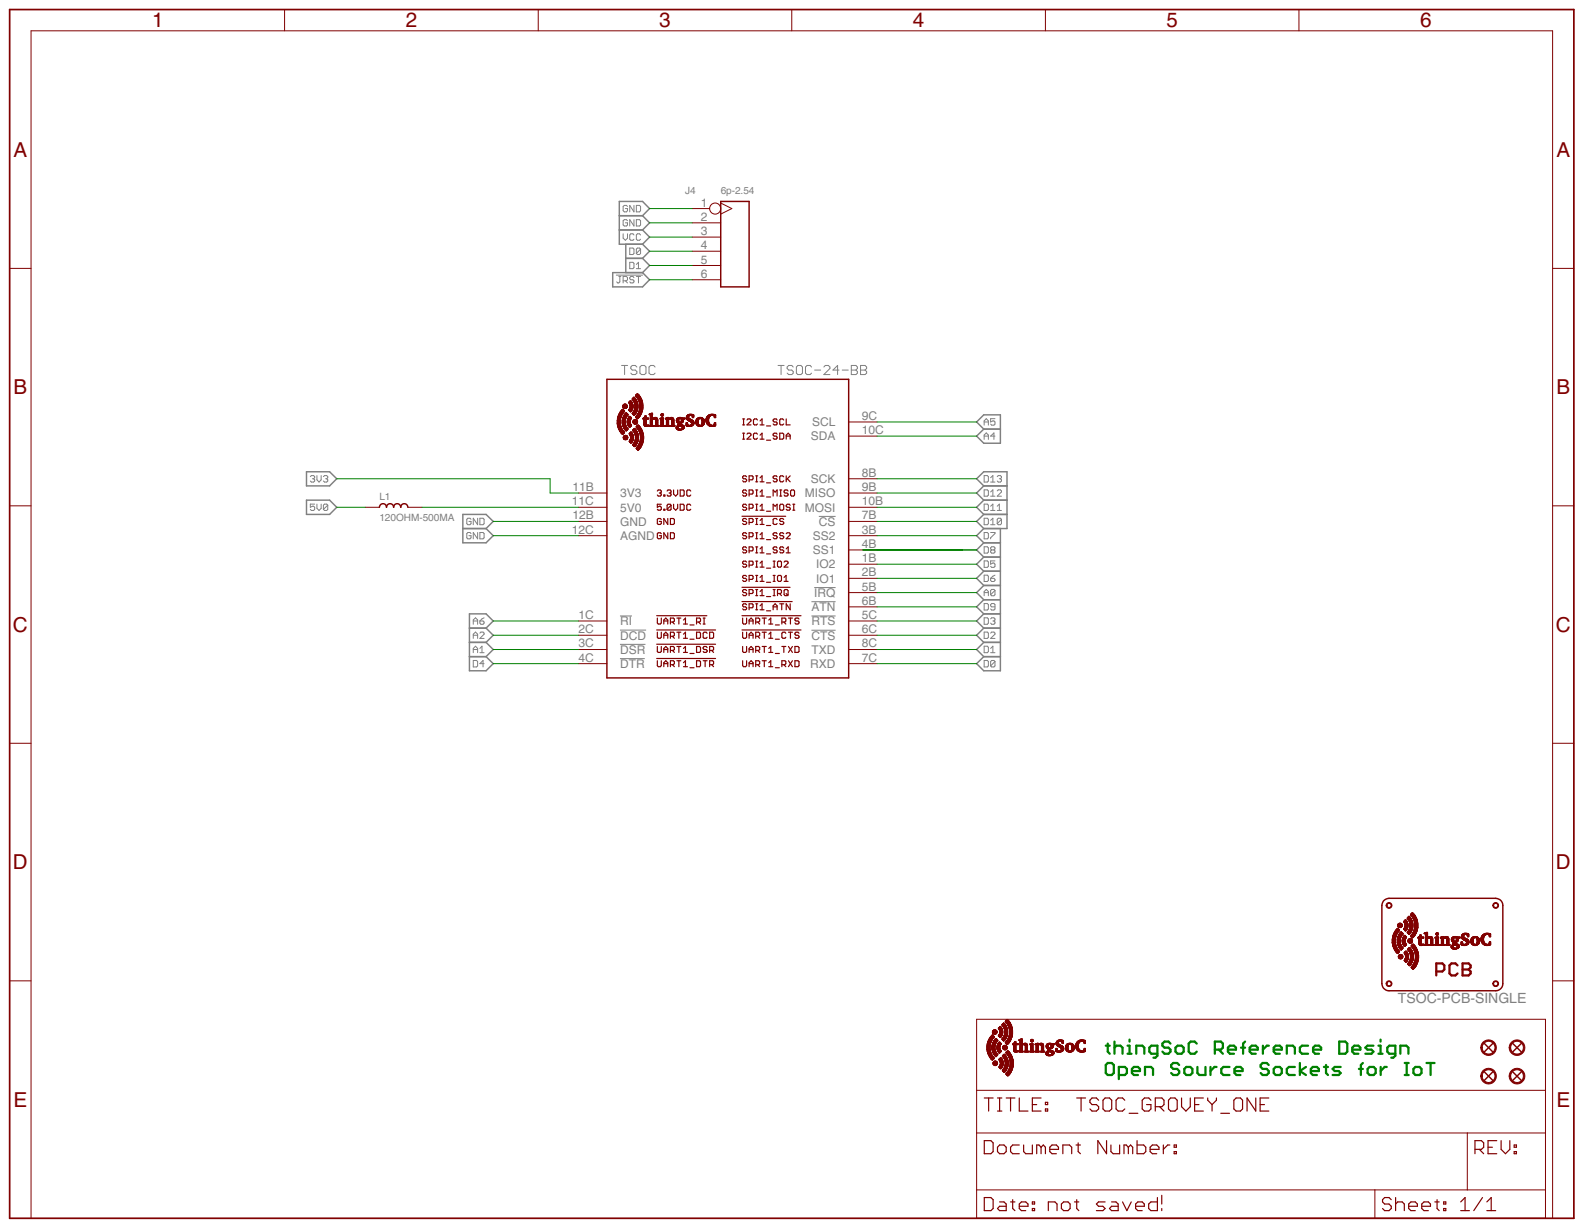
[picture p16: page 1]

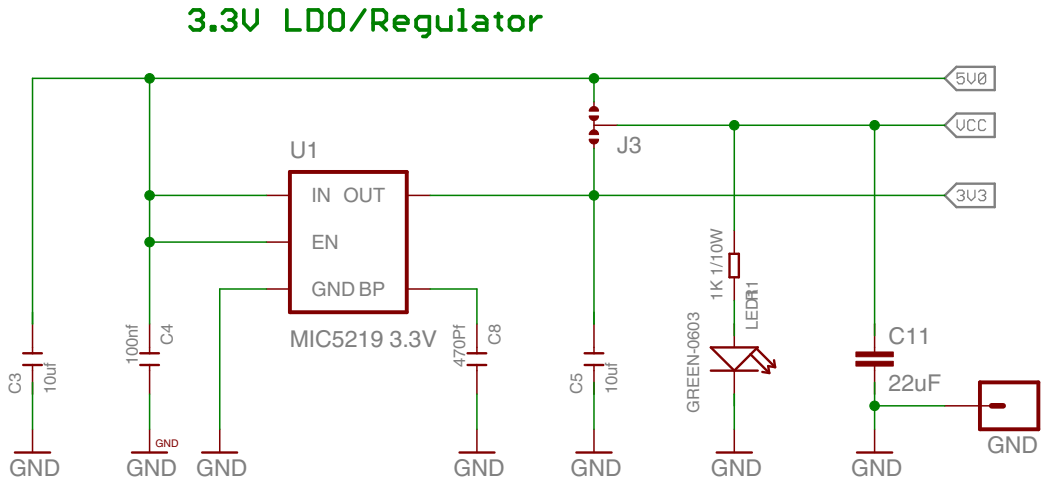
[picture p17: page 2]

100nf GND GND GND GND

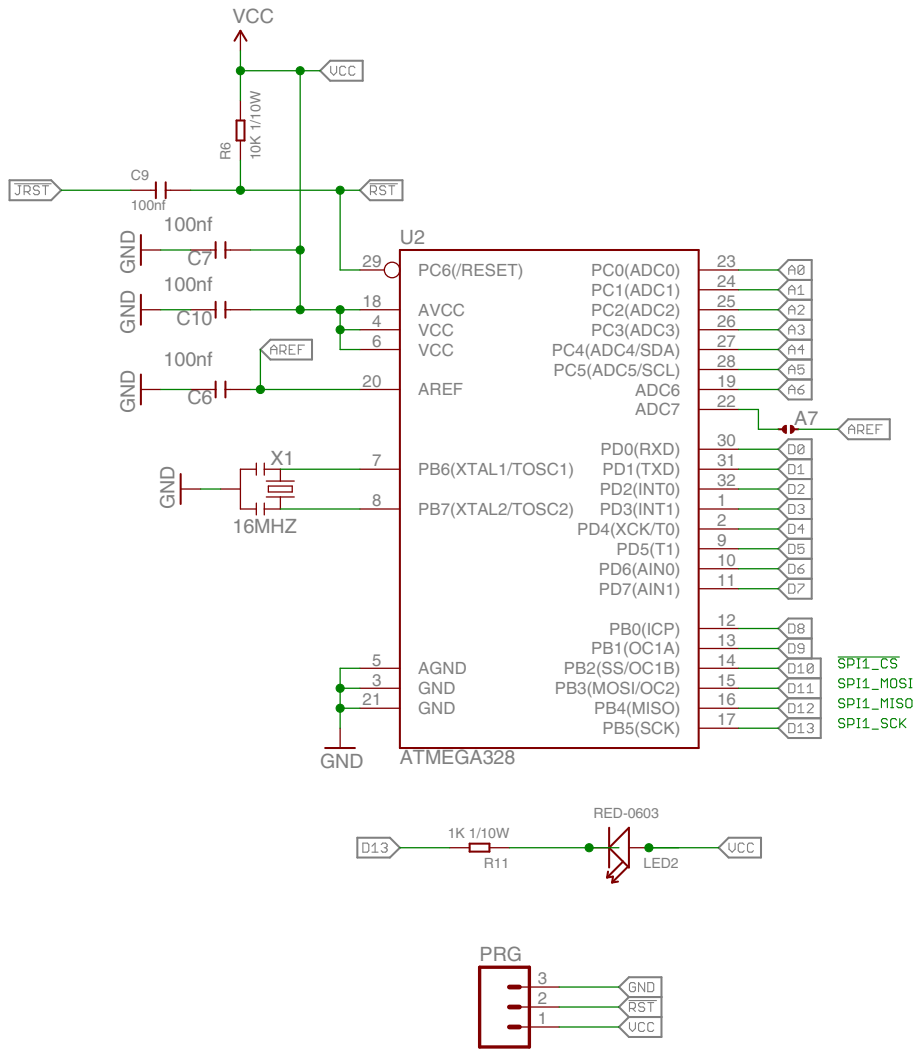
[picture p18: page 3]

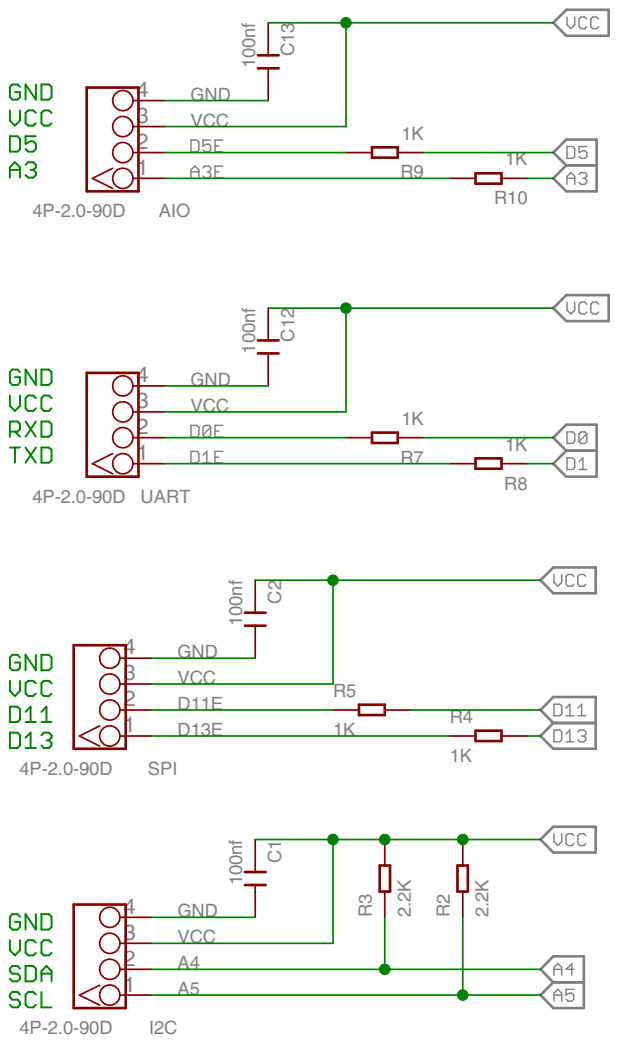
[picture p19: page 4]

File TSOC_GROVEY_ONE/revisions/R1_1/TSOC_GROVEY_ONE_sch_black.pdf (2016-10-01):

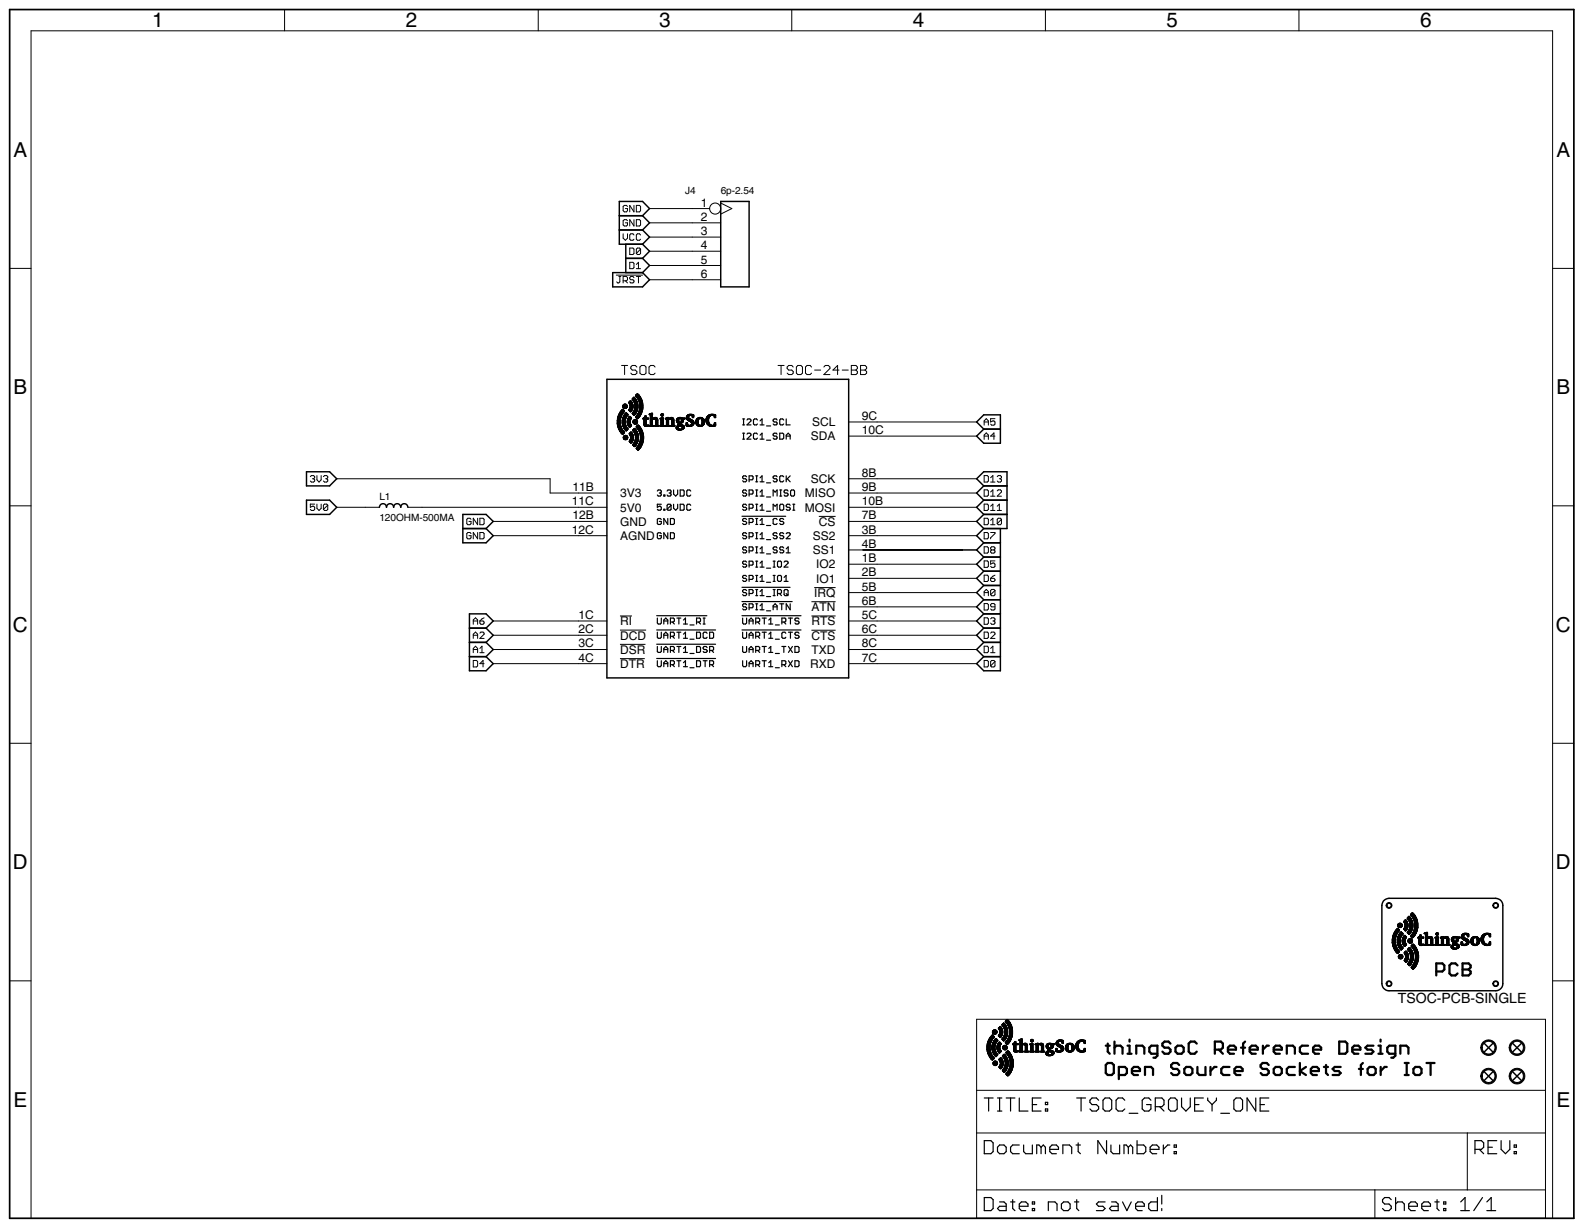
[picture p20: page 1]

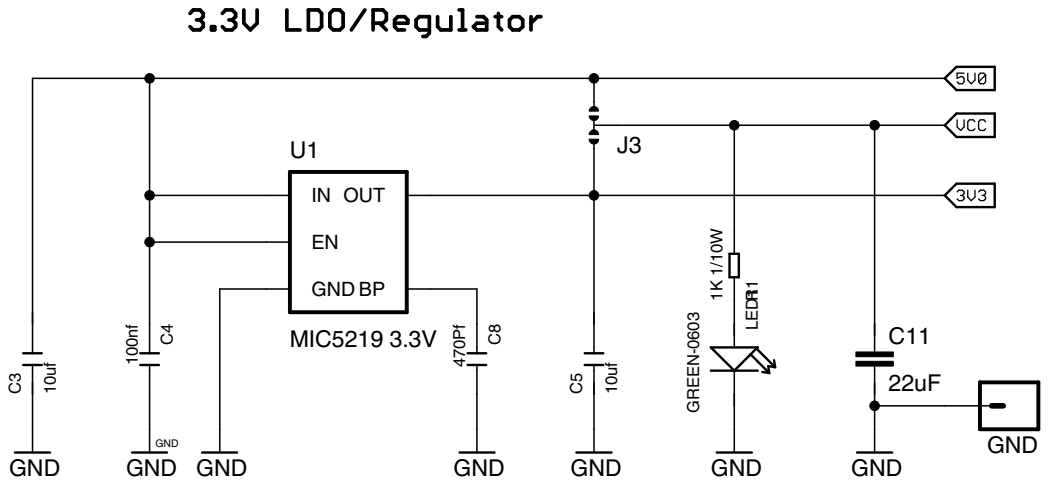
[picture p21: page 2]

100nf GND GND GND GND

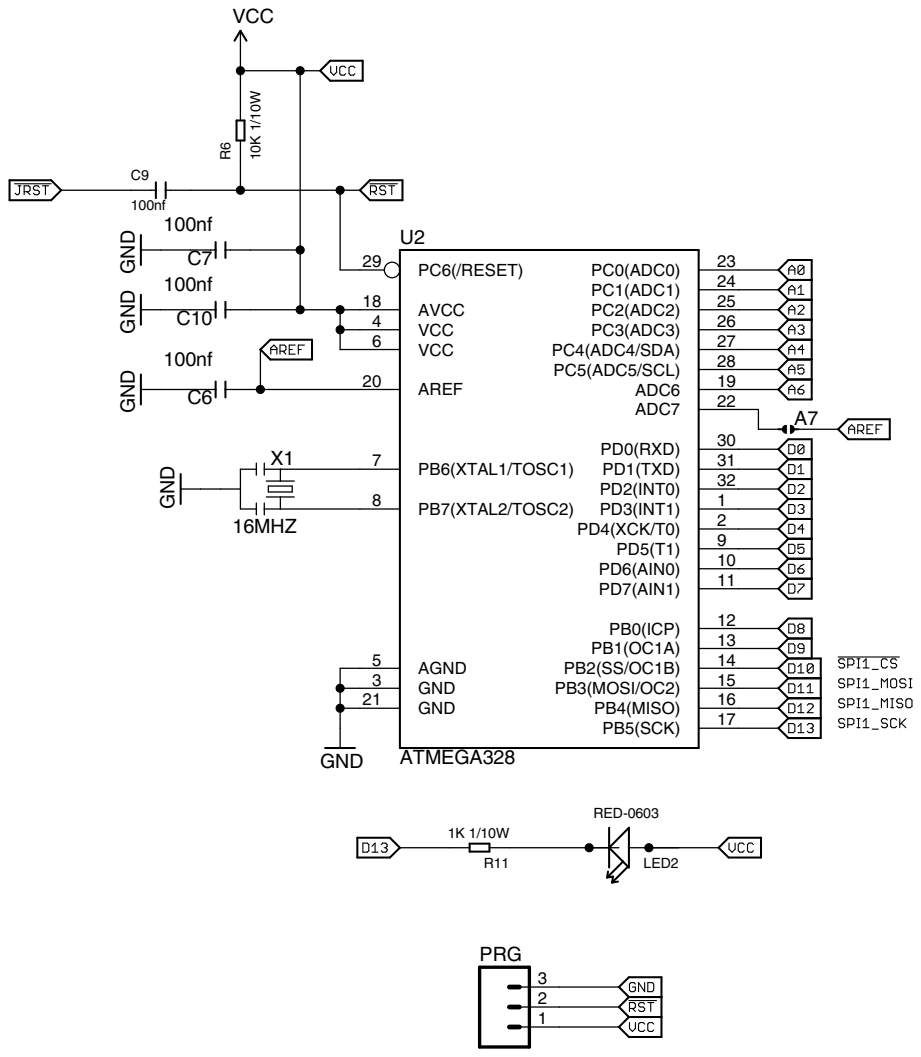
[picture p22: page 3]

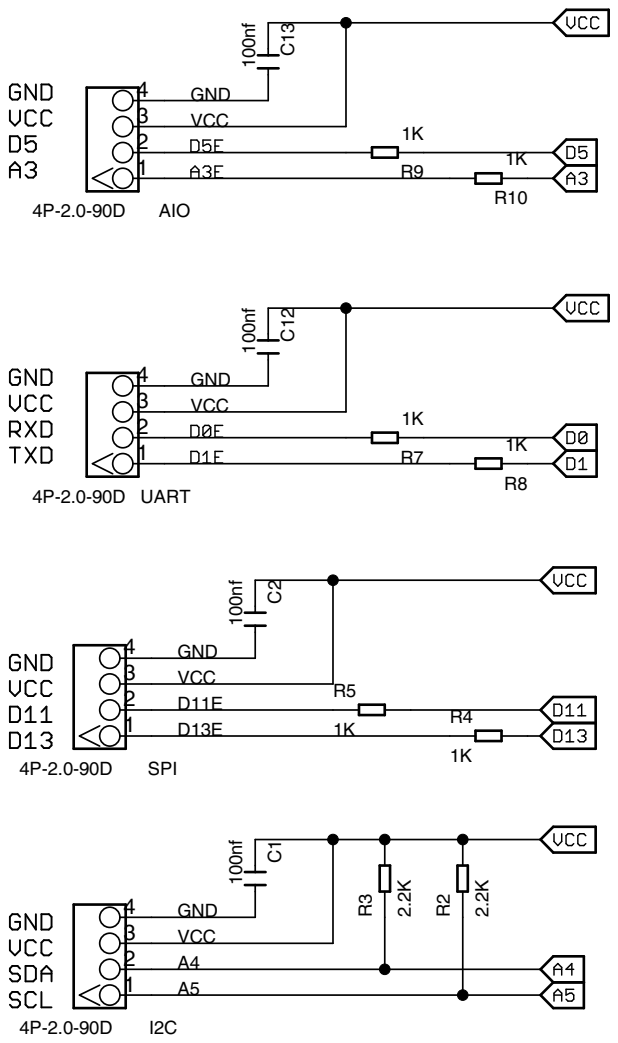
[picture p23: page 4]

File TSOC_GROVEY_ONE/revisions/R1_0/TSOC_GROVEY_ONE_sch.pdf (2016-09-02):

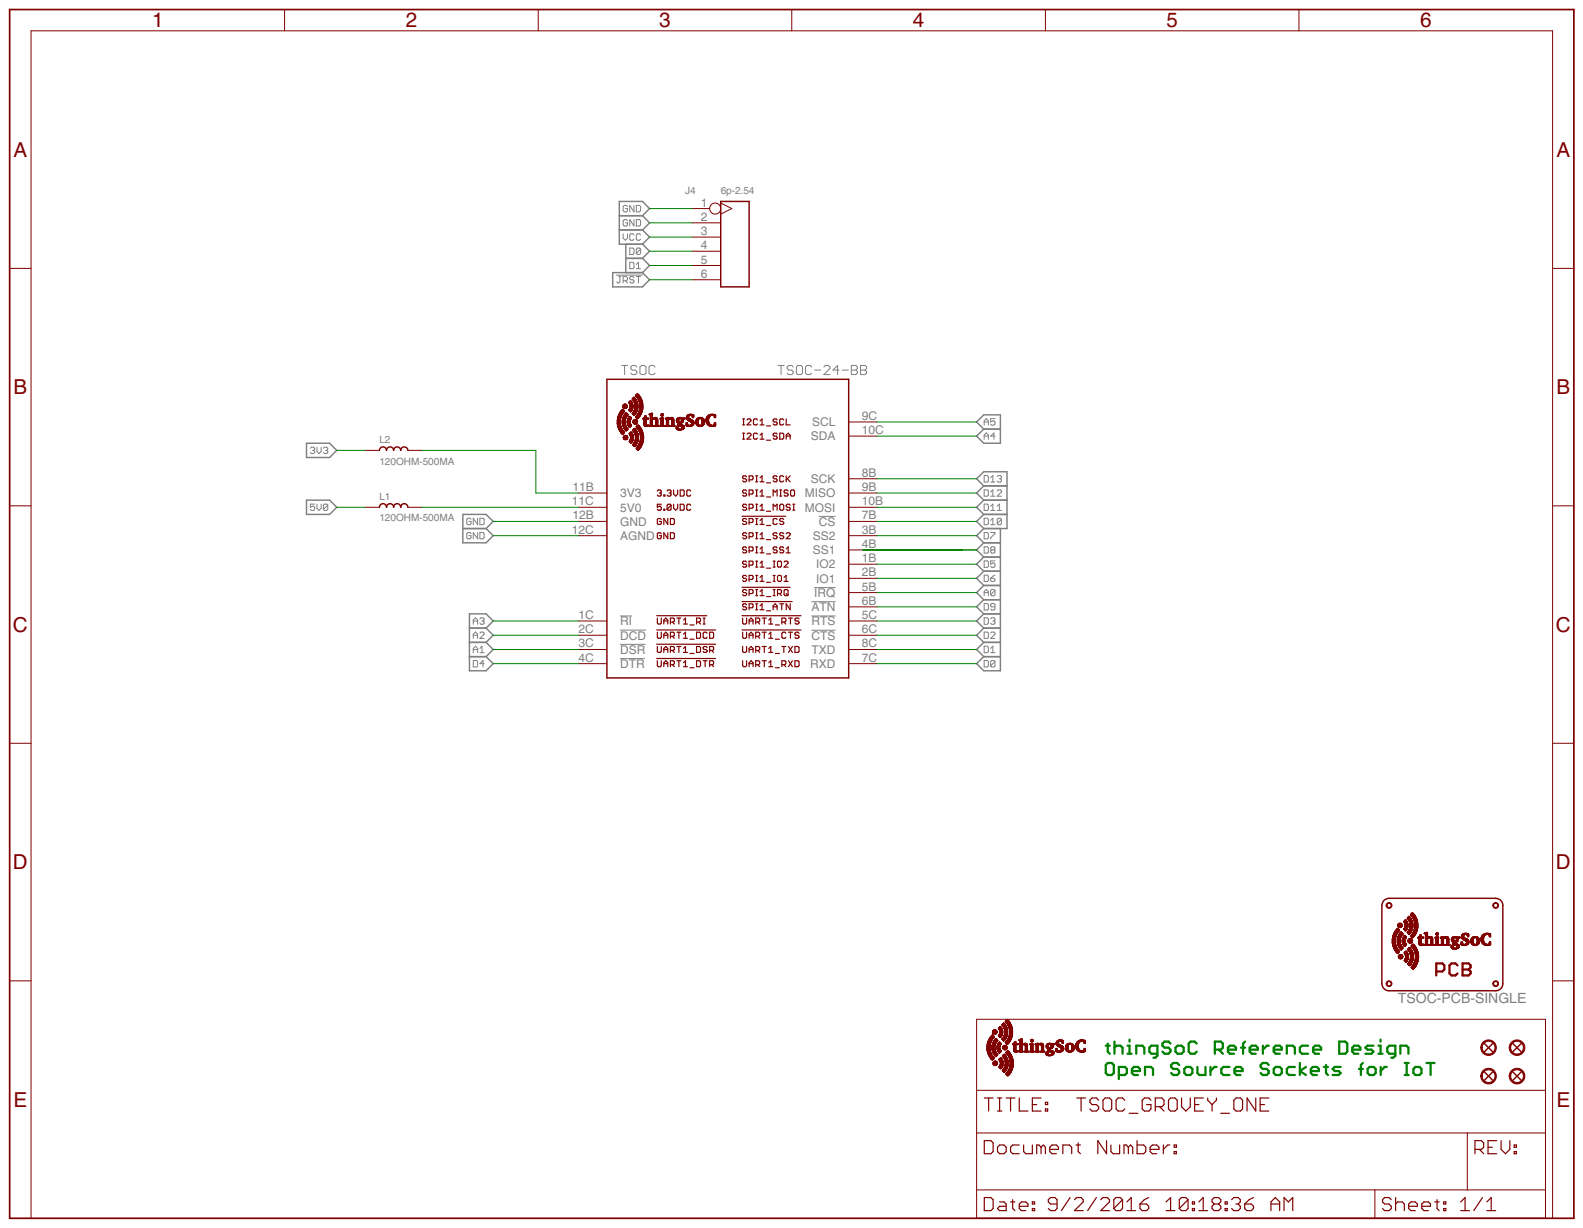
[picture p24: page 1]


100nf GND GND GND GND

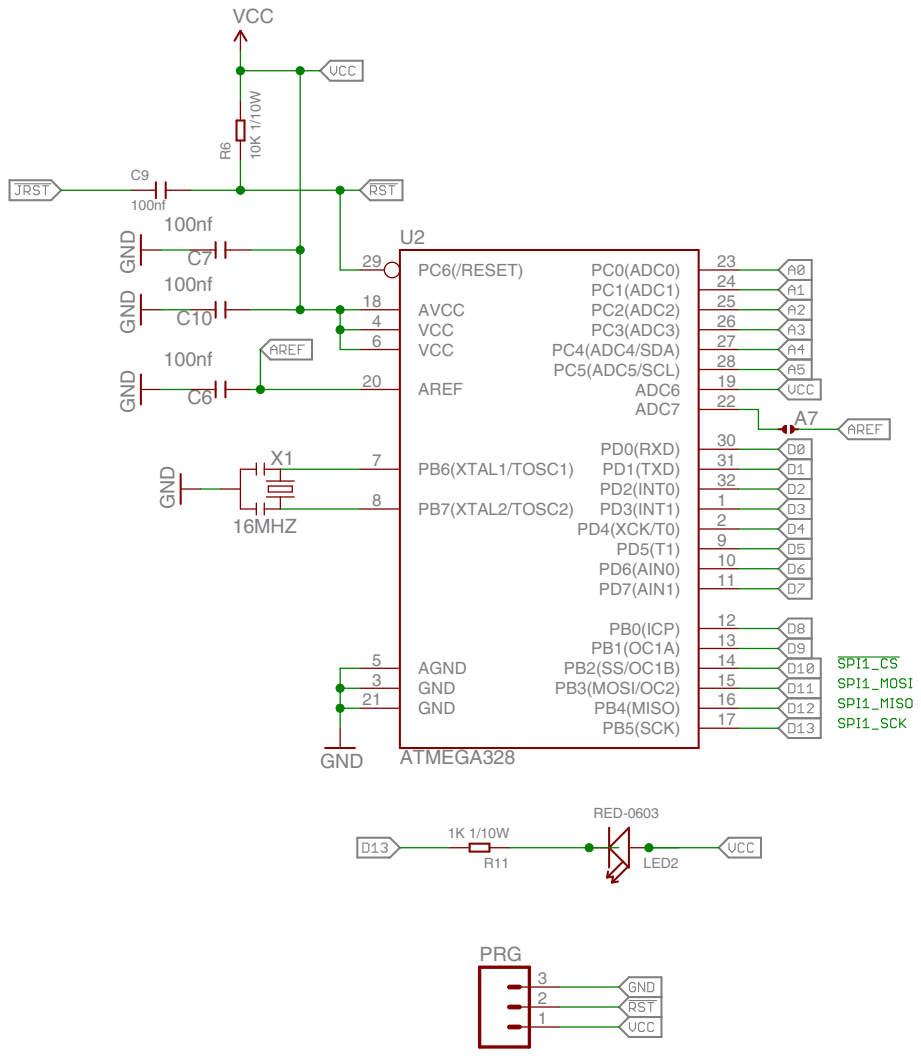
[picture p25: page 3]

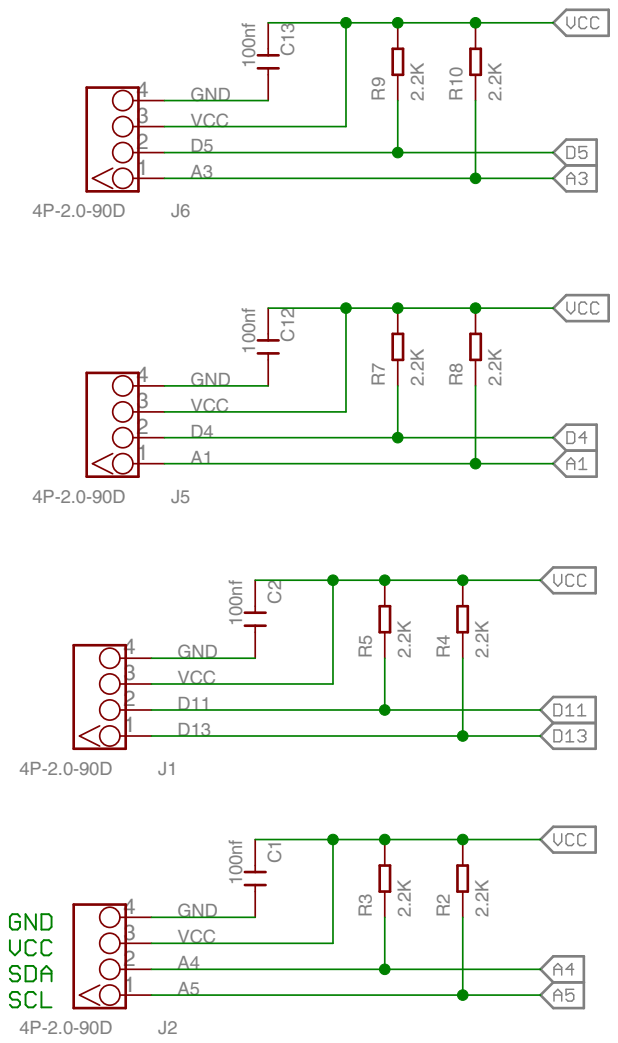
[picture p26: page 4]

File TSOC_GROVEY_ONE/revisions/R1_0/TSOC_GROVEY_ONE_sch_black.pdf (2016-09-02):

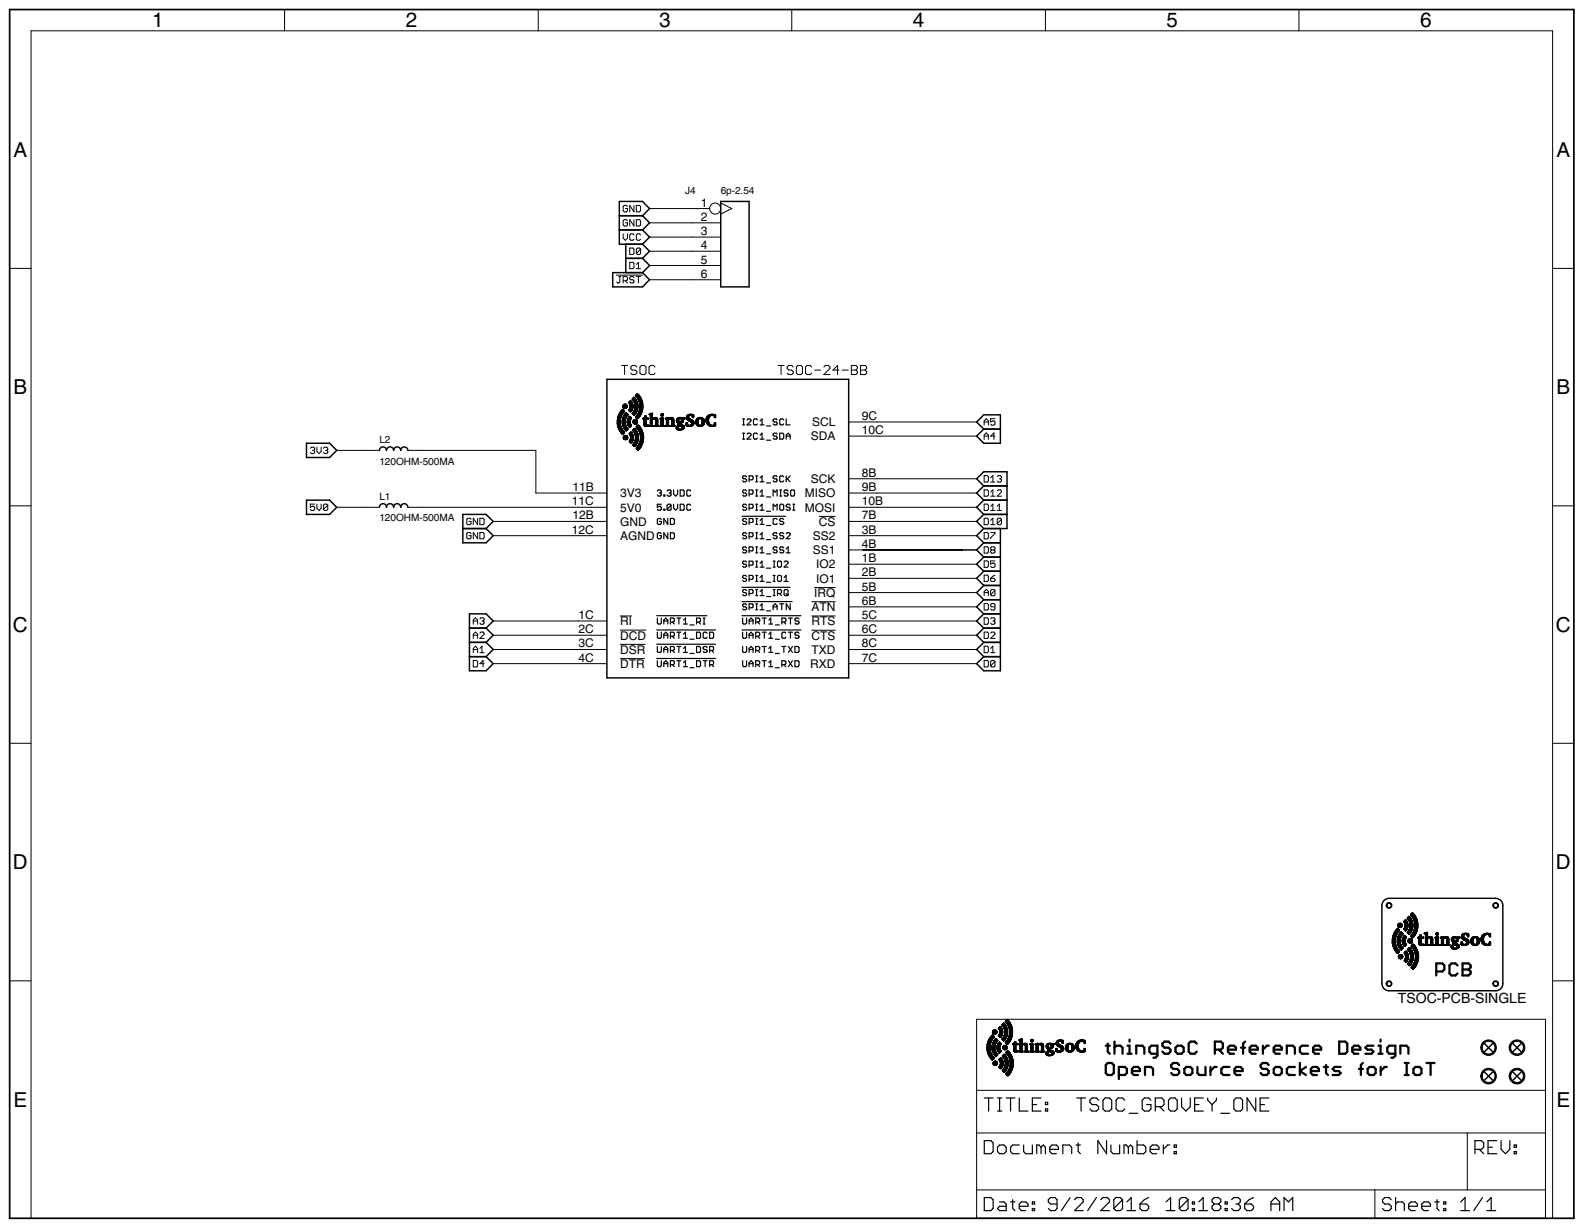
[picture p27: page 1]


100nf GND GND GND GND










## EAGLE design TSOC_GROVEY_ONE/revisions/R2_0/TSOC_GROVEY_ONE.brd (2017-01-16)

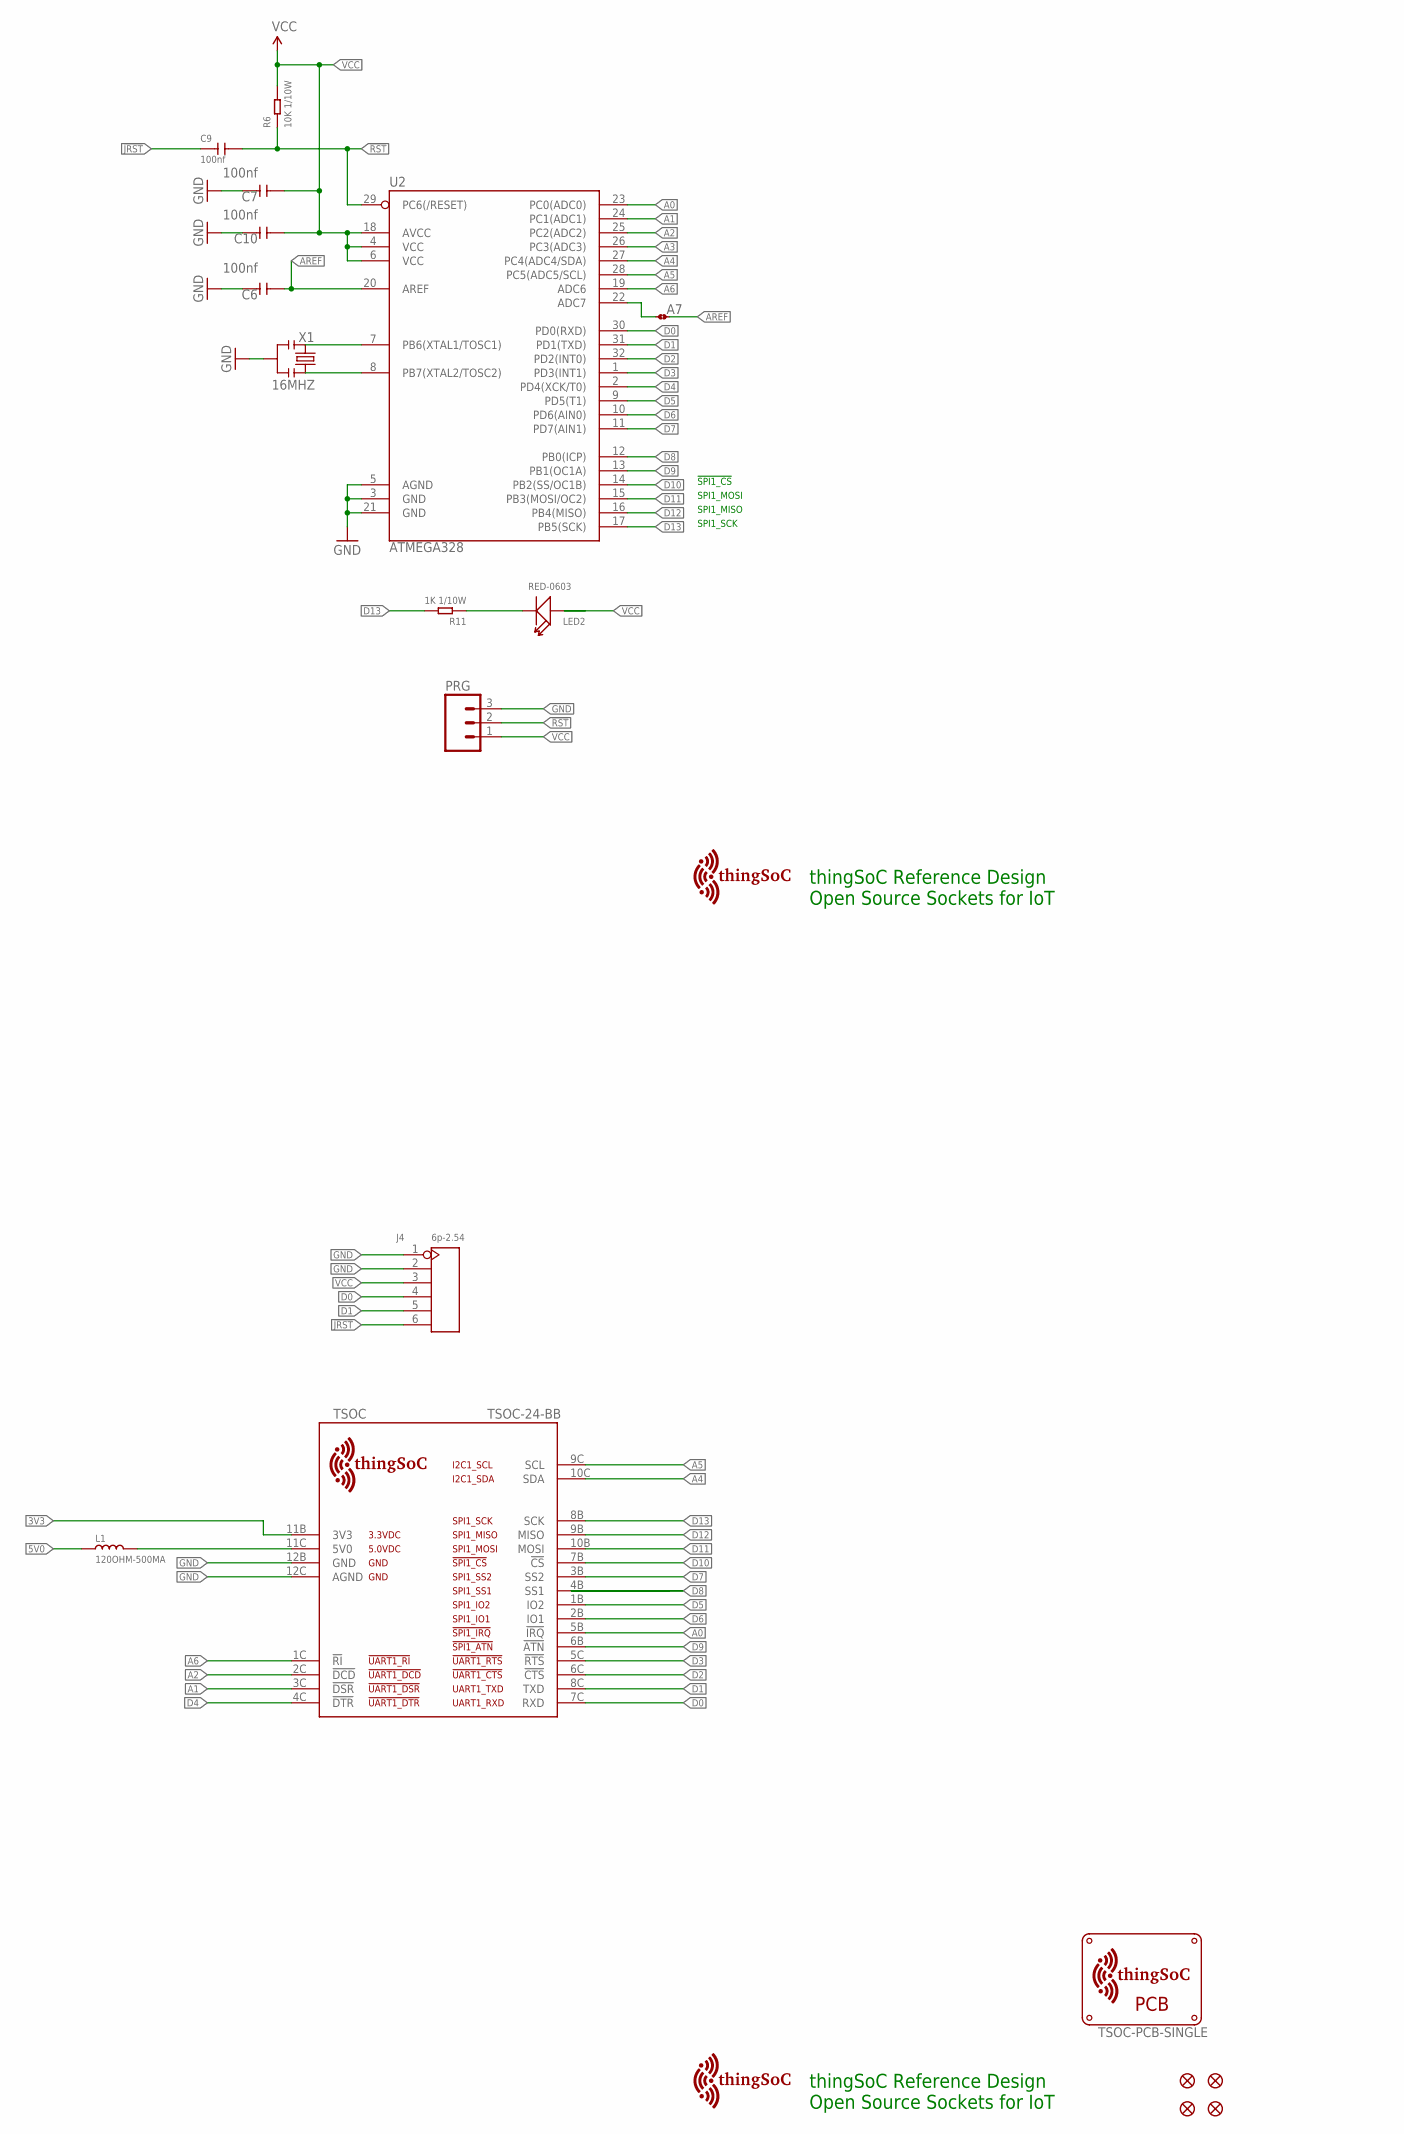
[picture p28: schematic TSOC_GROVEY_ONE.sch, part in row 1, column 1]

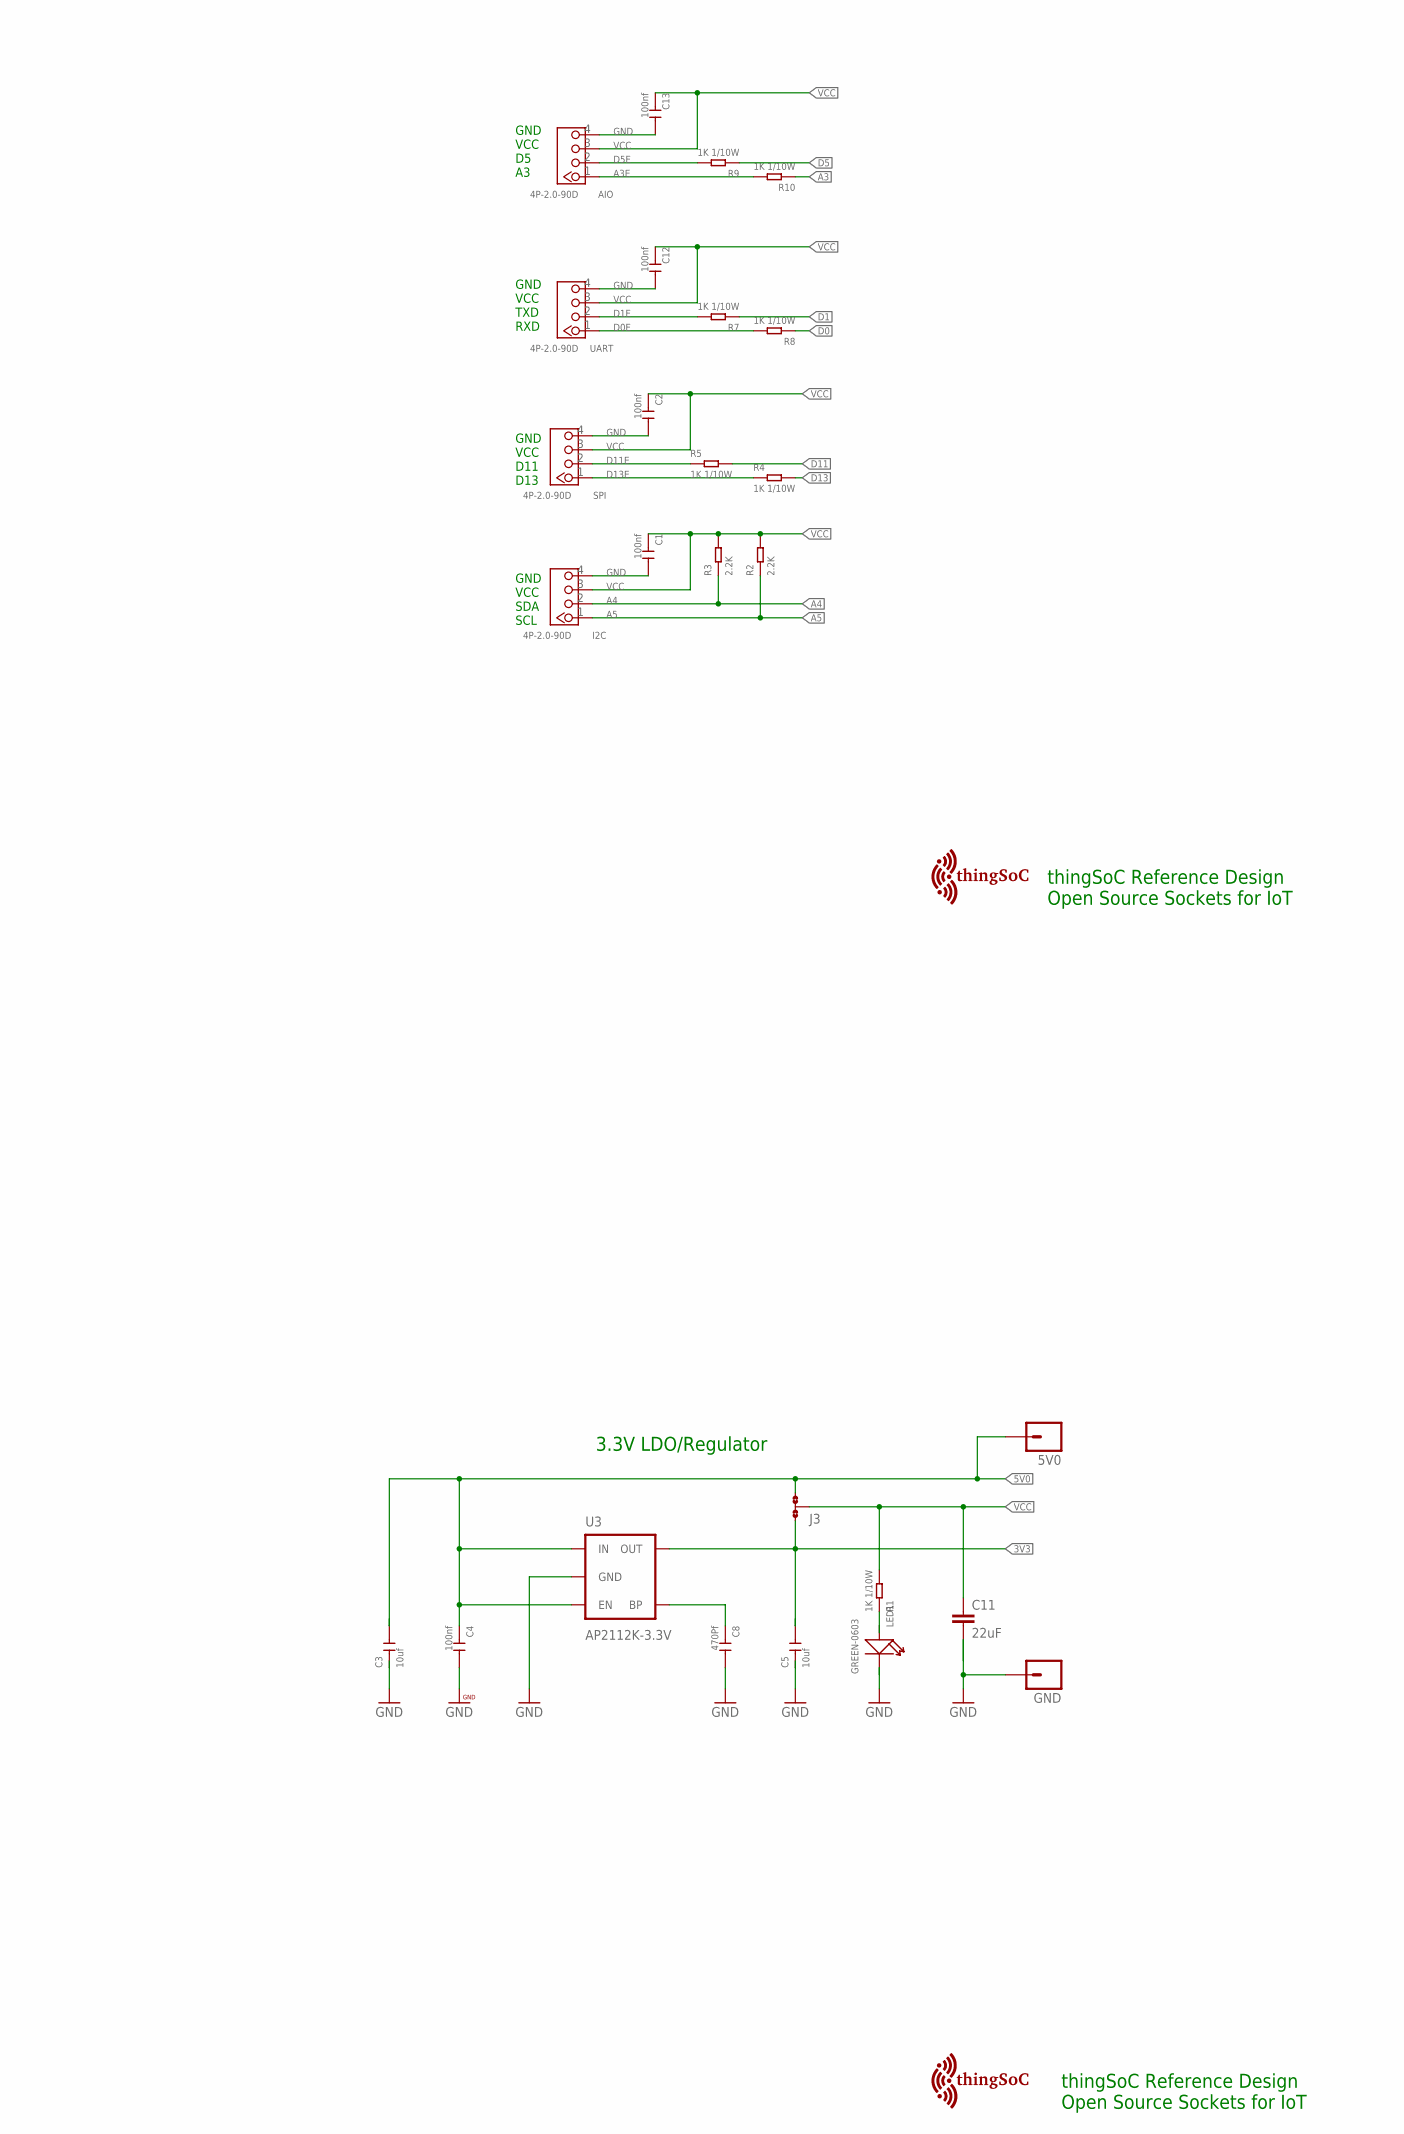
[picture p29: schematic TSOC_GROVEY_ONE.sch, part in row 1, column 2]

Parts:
5V0: M01PTH; 1X01
$$U$1: TSOC-PCB-SINGLE; TSOC-BB-BRD-DIM
A7: JMP-2-NO
AIO: 4P-2.0-90D; HW4-2.0-90D
C1, C2, C4, C6, C7, C9, C10, C12, C13: 100nf; C0603
C3, C5: 10uf; C0603
C8: 470Pf; C0603
C11: 22uF; EIA-1206
FID1, FID2, FID3, FID4: FIDUCIALUFIDUCIAL; MICRO-FIDUCIAL
GND: M01PTH; 1X01
I2C: 4P-2.0-90D; HW4-2.0-90D
J3: NO; JMP-3-NO-PTH-2.54
J4: 6p-2.54; H6-2.54
L1: 120OHM-500MA; L0603
LED1: GREEN-0603; LED-0603
LED2: RED-0603; LED-0603
PRG: M03PTH; 1X03
R1, R4, R5, R7, R8, R9, R10, R11: 1K 1/10W; R0603
R2, R3: 2.2K; R0603
R6: 10K 1/10W; R0603
SPI: 4P-2.0-90D; HW4-2.0-90D
TSOC: TSOC-24-BB; TSOC-BB-S24
U2: ATMEGA328; TQFP32-08
U3: AP2112K-3.3V; SOT23-5
U$1, U$101, U$103: TSOC-LOGO-SMALL; TSOC-LOGO-SML
U$102: TSOC-LOGO-LRG
UART: 4P-2.0-90D; HW4-2.0-90D
X1: 16MHZ; X3-SMD-3.6X1.3X0.8MM

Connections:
3V3: C5.2, J3.1, TSOC.11B (3V3), U3.5 (OUT)
5V0: 5V0.1, C3.2, C4.1, J3.3, L1.1, U3.1 (IN), U3.3 (EN)
!JRST: C9.1, J4.6
!RST: C9.2, PRG.2, R6.1, U2.29 (PC6(/RESET))
A0: TSOC.5B (!IRQ), U2.23 (PC0(ADC0))
A1: TSOC.3C (!DSR), U2.24 (PC1(ADC1))
A2: TSOC.2C (!DCD), U2.25 (PC2(ADC2))
A3: R10.1, U2.26 (PC3(ADC3))
A3E: AIO.1, R10.2
A4: I2C.2, R3.1, TSOC.10C (SDA), U2.27 (PC4(ADC4/SDA))
A5: I2C.1, R2.1, TSOC.9C (SCL), U2.28 (PC5(ADC5/SCL))
A6: TSOC.1C (!RI), U2.19 (ADC6)
A7: A7.1, U2.22 (ADC7)
AREF: A7.2, C6.2, U2.20 (AREF)
BYPASS1: C8.1, U3.4 (BP)
D0: J4.4, R8.1, TSOC.7C (RXD), U2.30 (PD0(RXD))
D0E: R8.2, UART.1
D1: J4.5, R7.1, TSOC.8C (TXD), U2.31 (PD1(TXD))
D1E: R7.2, UART.2
D2: TSOC.6C (!CTS), U2.32 (PD2(INT0))
D3: TSOC.5C (!RTS), U2.1 (PD3(INT1))
D4: TSOC.4C (!DTR), U2.2 (PD4(XCK/T0))
D5: R9.1, TSOC.1B (IO2), U2.9 (PD5(T1))
D5E: AIO.2, R9.2
D6: TSOC.2B (IO1), U2.10 (PD6(AIN0))
D7: TSOC.3B (SS2), U2.11 (PD7(AIN1))
D8: TSOC.4B (SS1), U2.12 (PB0(ICP))
D9: TSOC.6B (!ATN), U2.13 (PB1(OC1A))
D10: TSOC.7B (!CS), U2.14 (PB2(SS/OC1B))
D11: R5.2, TSOC.10B (MOSI), U2.15 (PB3(MOSI/OC2))
D11E: R5.1, SPI.2
D12: TSOC.9B (MISO), U2.16 (PB4(MISO))
D13: R4.2, R11.2, TSOC.8B (SCK), U2.17 (PB5(SCK))
D13E: R4.1, SPI.1
GND: AIO.4, C1.2, C2.2, C3.1, C4.2, C5.1, C6.1, C7.1, C8.2, C10.1, C11.2, C12.2, C13.2, GND.1, I2C.4, J4.1, J4.2, LED1.-, PRG.3, SPI.4, TSOC.12B (GND), TSOC.12C (AGND), U2.3 (GND), U2.5 (AGND), U2.21 (GND), U3.2 (GND), UART.4, X1.2
LEDR: LED2.-, R11.1
unnamed: LED1.+, R1.1
TSOC_5V0: L1.2, TSOC.11C (5V0)
VCC: AIO.3, C1.1, C2.1, C7.2, C10.2, C11.1, C12.1, C13.1, I2C.3, J3.2, J4.3, LED2.+, PRG.1, R1.2, R2.2, R3.2, R6.2, SPI.3, U2.4 (VCC), U2.6 (VCC), U2.18 (AVCC), UART.3
XIN: U2.7 (PB6(XTAL1/TOSC1)), X1.3
XOUT: U2.8 (PB7(XTAL2/TOSC2)), X1.1

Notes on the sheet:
thingSoC Reference Design Open Source Sockets for IoT
SPI1_SCK
SPI1_MISO
SPI1_MOSI
!SPI1_CS
3.3V LDO/Regulator
SDA
SCL
VCC
GND
RXD
TXD
D11
D13

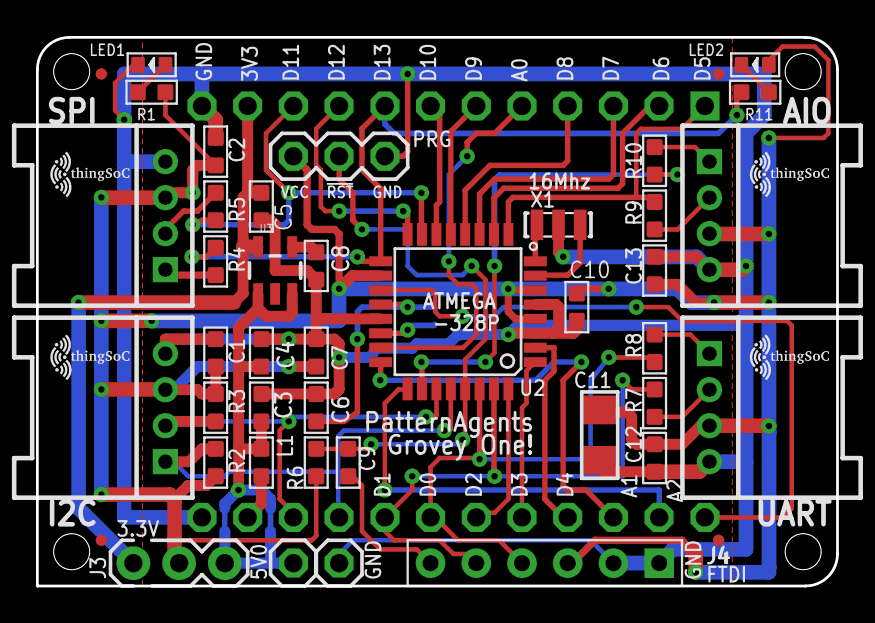
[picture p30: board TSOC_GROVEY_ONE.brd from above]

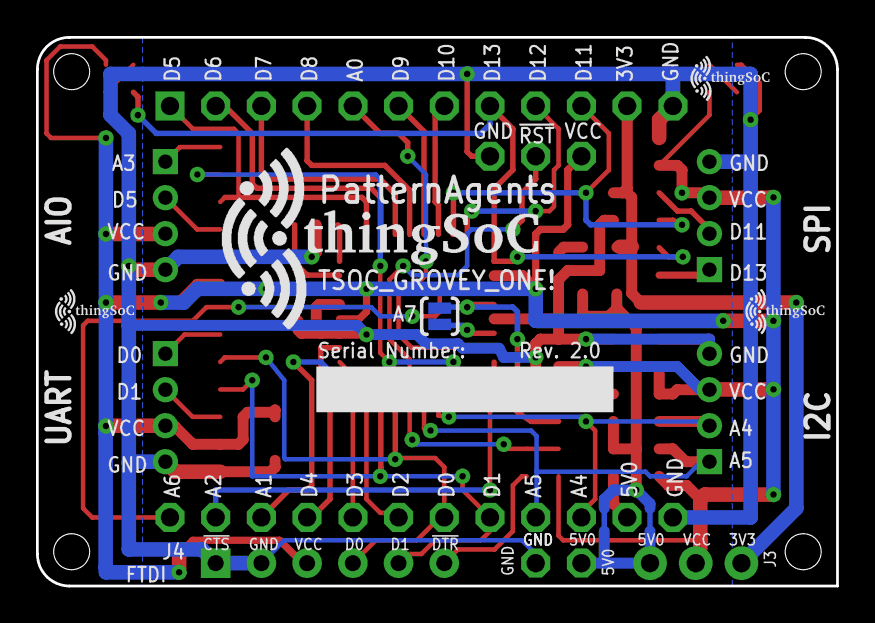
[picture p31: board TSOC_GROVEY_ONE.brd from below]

Board: 2 copper layers, 44.5 x 30.5 mm, 54 parts (5 on the bottom side), 41 nets.

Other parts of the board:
$$U$2, $$U$3: TSOC-LOGO-SMALL; TSOC-LOGO-SML
U$3, U$100: TSOC-LOGO-SMALL; TSOC-LOGO-SML

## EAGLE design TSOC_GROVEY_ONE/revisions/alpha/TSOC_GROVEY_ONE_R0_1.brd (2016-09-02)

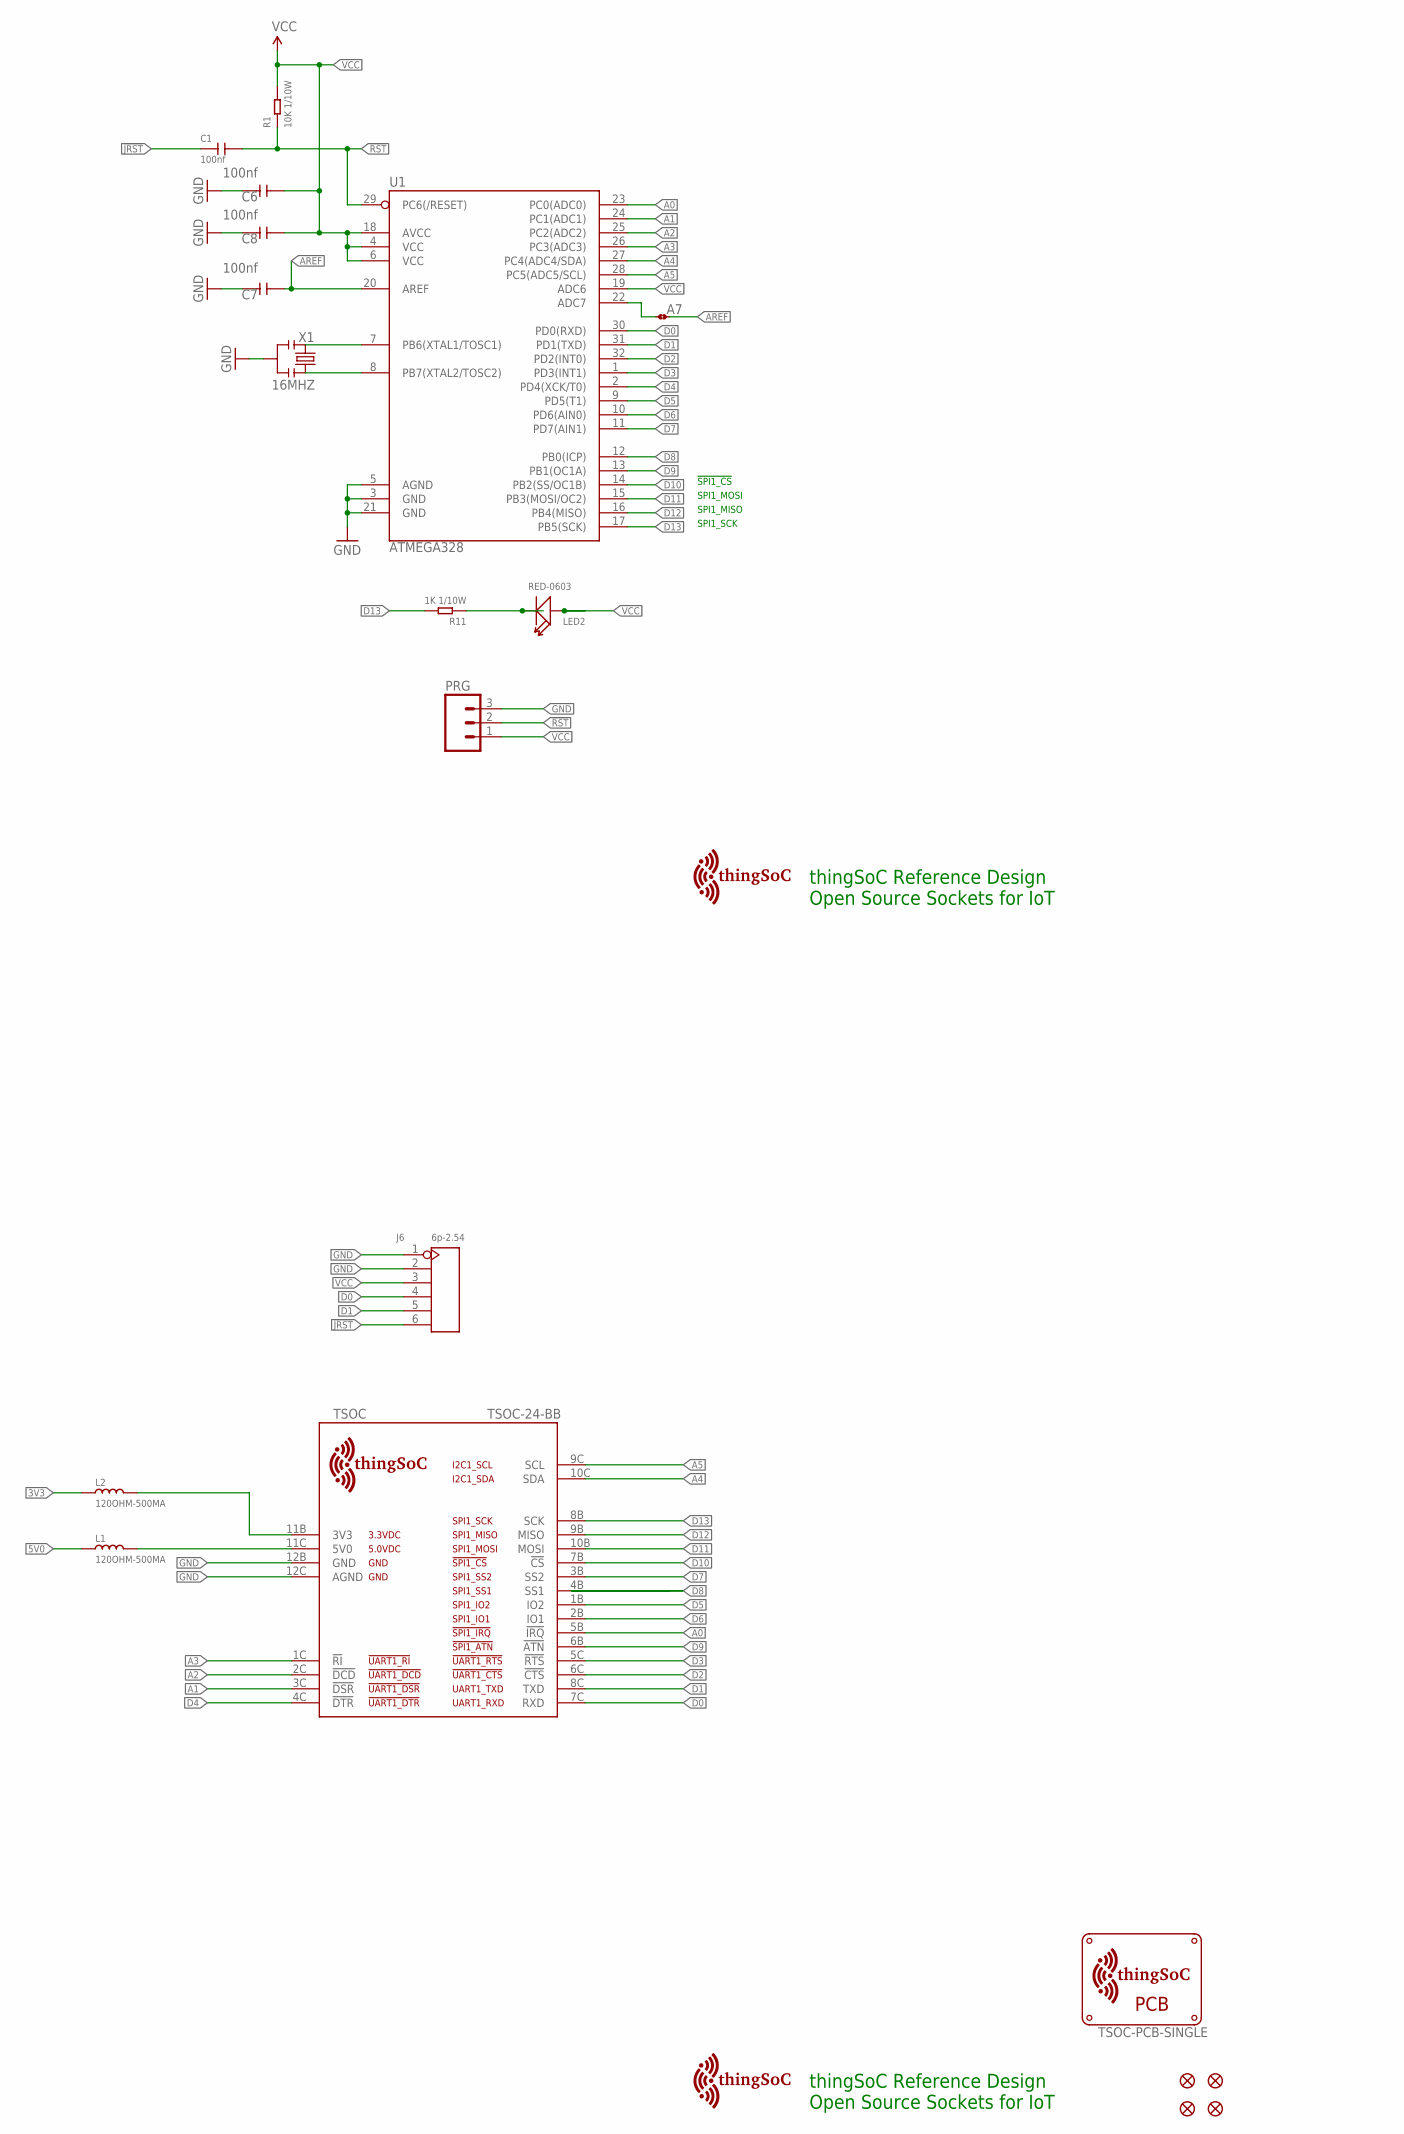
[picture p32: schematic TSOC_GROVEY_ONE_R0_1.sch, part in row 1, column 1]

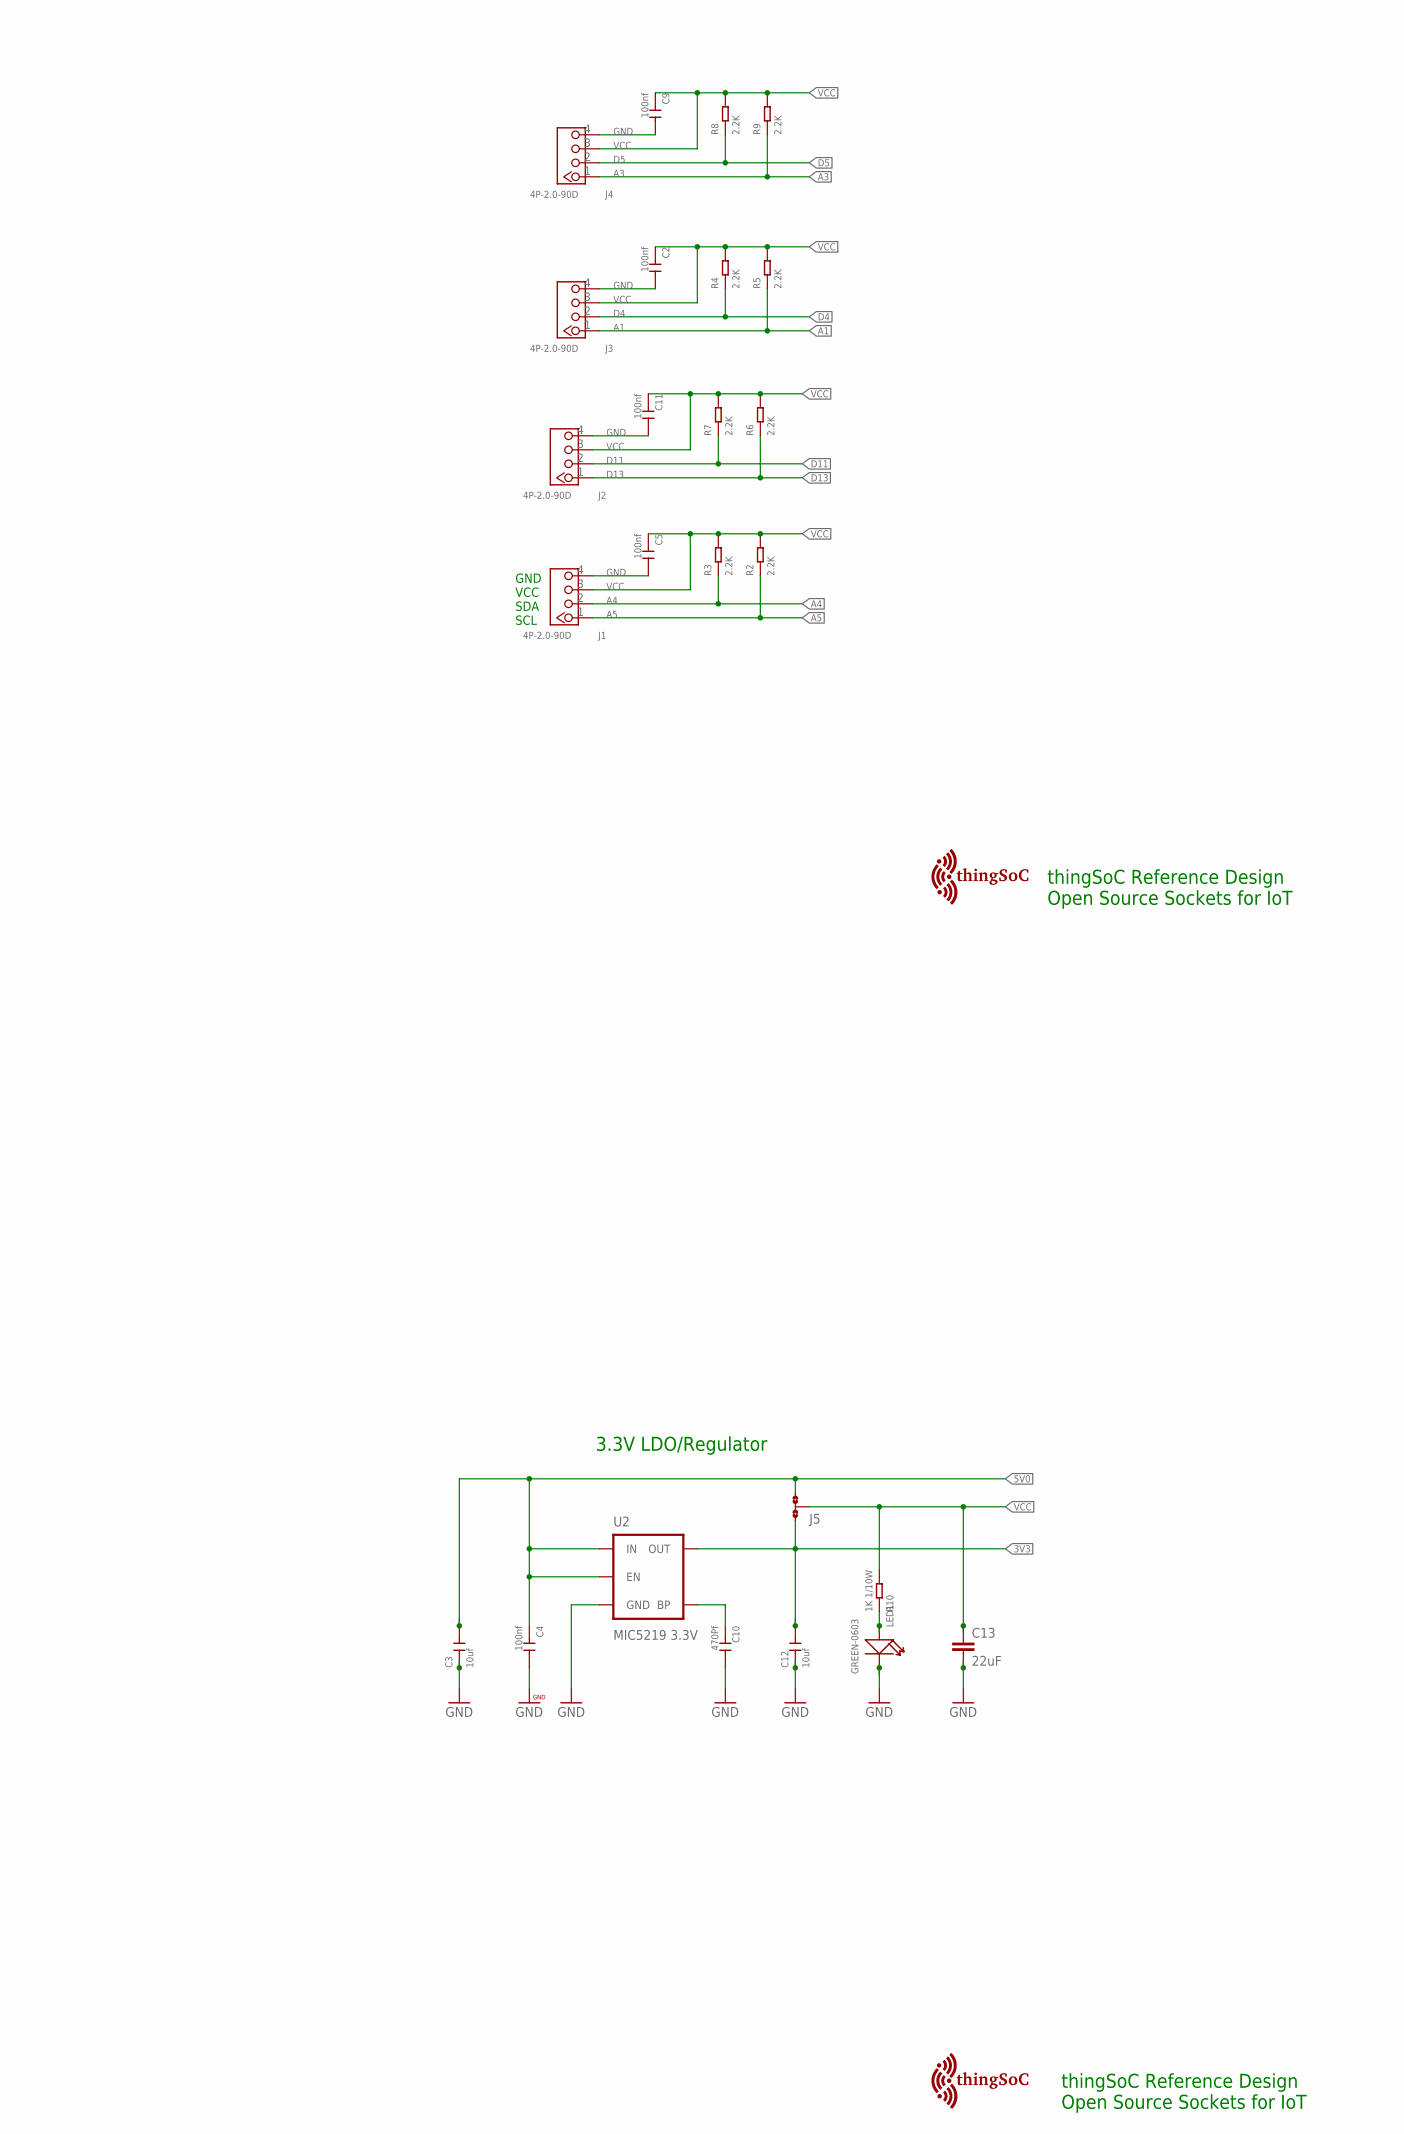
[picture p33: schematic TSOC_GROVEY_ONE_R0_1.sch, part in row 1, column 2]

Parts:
$$U$2: TSOC-PCB-SINGLE; TSOC-BB-BRD-DIM
A7: JMP-2-NO
C1, C2, C4, C5, C6, C7, C8, C9, C11: 100nf; C0603
C3, C12: 10uf; C0603
C10: 470Pf; C0603
C13: 22uF; EIA-1206
FID1, FID2, FID3, FID4: FIDUCIALUFIDUCIAL; MICRO-FIDUCIAL
J1, J2, J3, J4: 4P-2.0-90D; HW4-2.0-90D
J5: NO; JMP-3-NO-PTH-2.54
J6: 6p-2.54; H6-2.54
L1, L2: 120OHM-500MA; L0603
LED1: GREEN-0603; LED-0603
LED2: RED-0603; LED-0603
PRG: M03PTH; 1X03
R1: 10K 1/10W; R0603
R2, R3, R4, R5, R6, R7, R8, R9: 2.2K; R0603
R10, R11: 1K 1/10W; R0603
TSOC: TSOC-24-BB; TSOC-BB-S24
U1: ATMEGA328; TQFP32-08
U2: MIC5219 3.3V; SOT23-5
U$3, U$100, U$103: TSOC-LOGO-SMALL; TSOC-LOGO-SML
U$101: TSOC-LOGO-LRG
X1: 16MHZ; X3-SMD-3.6X1.3X0.8MM

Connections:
3V3: C12.2, J5.1, L2.1, U2.5 (OUT)
5V0: C3.2, C4.1, J5.3, L1.1, U2.1 (IN), U2.3 (EN)
!JRST: C1.1, J6.6
!RST: C1.2, PRG.2, R1.1, U1.29 (PC6(/RESET))
A0: TSOC.5B (!IRQ), U1.23 (PC0(ADC0))
A1: J3.1, R5.1, TSOC.3C (!DSR), U1.24 (PC1(ADC1))
A2: TSOC.2C (!DCD), U1.25 (PC2(ADC2))
A3: J4.1, R9.1, TSOC.1C (!RI), U1.26 (PC3(ADC3))
A4: J1.2, R3.1, TSOC.10C (SDA), U1.27 (PC4(ADC4/SDA))
A5: J1.1, R2.1, TSOC.9C (SCL), U1.28 (PC5(ADC5/SCL))
A7: A7.1, U1.22 (ADC7)
AREF: A7.2, C7.2, U1.20 (AREF)
BYPASS1: C10.1, U2.4 (BP)
D0: J6.4, TSOC.7C (RXD), U1.30 (PD0(RXD))
D1: J6.5, TSOC.8C (TXD), U1.31 (PD1(TXD))
D2: TSOC.6C (!CTS), U1.32 (PD2(INT0))
D3: TSOC.5C (!RTS), U1.1 (PD3(INT1))
D4: J3.2, R4.1, TSOC.4C (!DTR), U1.2 (PD4(XCK/T0))
D5: J4.2, R8.1, TSOC.1B (IO2), U1.9 (PD5(T1))
D6: TSOC.2B (IO1), U1.10 (PD6(AIN0))
D7: TSOC.3B (SS2), U1.11 (PD7(AIN1))
D8: TSOC.4B (SS1), U1.12 (PB0(ICP))
D9: TSOC.6B (!ATN), U1.13 (PB1(OC1A))
D10: TSOC.7B (!CS), U1.14 (PB2(SS/OC1B))
D11: J2.2, R7.1, TSOC.10B (MOSI), U1.15 (PB3(MOSI/OC2))
D12: TSOC.9B (MISO), U1.16 (PB4(MISO))
D13: J2.1, R6.1, R11.2, TSOC.8B (SCK), U1.17 (PB5(SCK))
GND: C2.2, C3.1, C4.2, C5.2, C6.1, C7.1, C8.1, C9.2, C10.2, C11.2, C12.1, C13.2, J1.4, J2.4, J3.4, J4.4, J6.1, J6.2, LED1.-, PRG.3, TSOC.12B (GND), TSOC.12C (AGND), U1.3 (GND), U1.5 (AGND), U1.21 (GND), U2.2 (GND), X1.2
LEDR: LED2.-, R11.1
unnamed: LED1.+, R10.1
TSOC_3V3: L2.2, TSOC.11B (3V3)
TSOC_5V0: L1.2, TSOC.11C (5V0)
VCC: C2.1, C5.1, C6.2, C8.2, C9.1, C11.1, C13.1, J1.3, J2.3, J3.3, J4.3, J5.2, J6.3, LED2.+, PRG.1, R1.2, R2.2, R3.2, R4.2, R5.2, R6.2, R7.2, R8.2, R9.2, R10.2, U1.4 (VCC), U1.6 (VCC), U1.18 (AVCC), U1.19 (ADC6)
XIN: U1.7 (PB6(XTAL1/TOSC1)), X1.3
XOUT: U1.8 (PB7(XTAL2/TOSC2)), X1.1

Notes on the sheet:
thingSoC Reference Design Open Source Sockets for IoT
SPI1_SCK
SPI1_MISO
SPI1_MOSI
!SPI1_CS
3.3V LDO/Regulator
SDA
SCL
VCC
GND

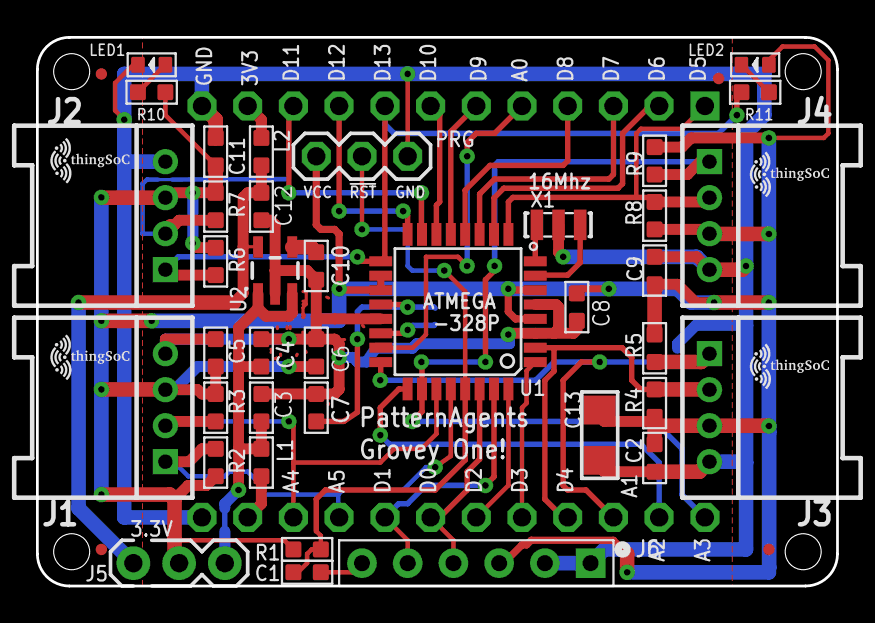
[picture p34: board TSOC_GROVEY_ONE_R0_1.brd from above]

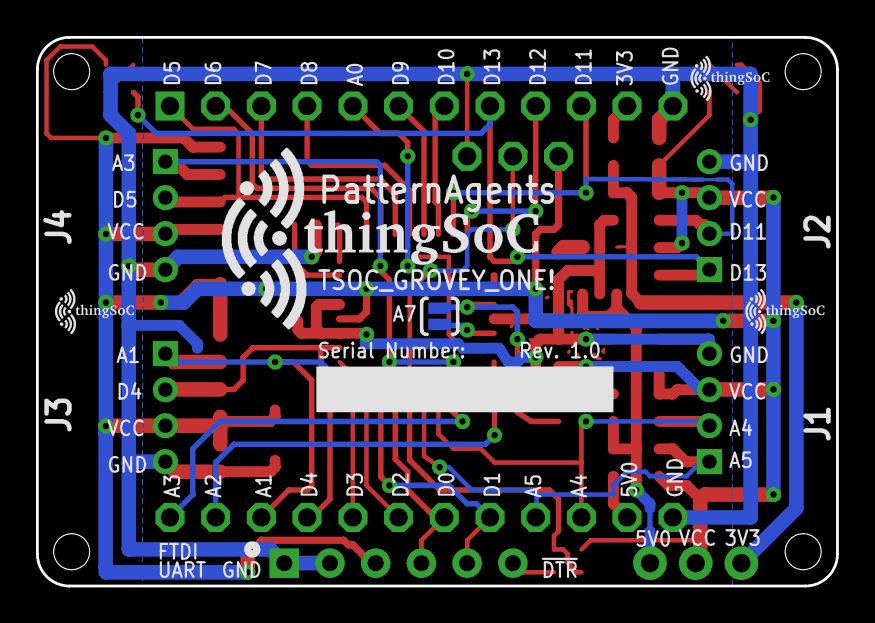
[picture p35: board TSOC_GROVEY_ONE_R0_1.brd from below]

Board: 2 copper layers, 44.5 x 30.5 mm, 53 parts (5 on the bottom side), 35 nets.

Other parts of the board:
U$1, U$4, U$5, U$102: TSOC-LOGO-SMALL; TSOC-LOGO-SML

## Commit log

2016-09-02 initial version
    [TSOC_GROVEY_ONE.brd, TSOC_GROVEY_ONE.sch, TSOC_GROVEY_ONE.skp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]
2016-10-01 update to Rev 2.0
    [TSOC_GROVEY_ONE.brd, TSOC_GROVEY_ONE.sch, TSOC_GROVEY_ONE.skp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]
2017-01-16 update documetation
    [TSOC_GROVEY_ONE.brd, TSOC_GROVEY_ONE.sch, TSOC_GROVEY_ONE.skp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]

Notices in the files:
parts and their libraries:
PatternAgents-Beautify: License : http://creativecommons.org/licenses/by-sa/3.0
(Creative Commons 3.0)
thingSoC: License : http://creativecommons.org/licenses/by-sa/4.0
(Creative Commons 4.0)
